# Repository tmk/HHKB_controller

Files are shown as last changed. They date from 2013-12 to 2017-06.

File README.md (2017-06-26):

Keyboard Controller Board for HHKB
==================================
This controller makes your HHKB fully programmable. You can use this with [tmk_keyboard] firmware. This will fit HHKB Pro2, Type-S and JP.

[tmk_keyboard]: https://github.com/tmk/tmk_keyboard

You can buy assembled board here. https://geekhack.org/index.php?topic=71517.0

dimension
----
141.50x36.00mm(1.6mm thick)

Update
------
- 2017/06/27: Rev.N     Fix footprint of USB: add SMD pads for frame
- 2017/05/03: Rev.M     Fix footprints of USB, LED, SKHH and DF14
- 2016/08/27: Rev.L     Enlarge TH land of USB connector
- 2016/07/03: Rev.K     Add reverse polarity protection and change foot print of D1
- 2016/01/28: Rev.J     Add TMK logo and remove C13
- 2015/12/01: Rev.I     Changed USB miniB to UX60SC-MB-5S8(through hole)
- 2015/12/01: Rev.H'    Changed lands of USB miniB to recomended size
- 2015/07/xx: Rev.H
- 2015/03/xx: Rev.G
- 2014/12/xx: Rev.F
- 2014/11/xx: Rev.E
- 2014/09/19: Rev.D
- 2014/07/28: Rev.C

LICENSE
-------
TBD

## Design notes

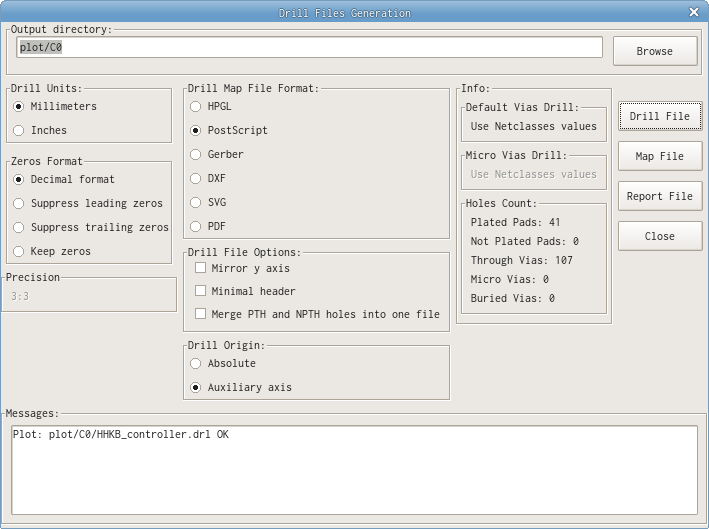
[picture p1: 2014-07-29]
plot/Drill_setting.png

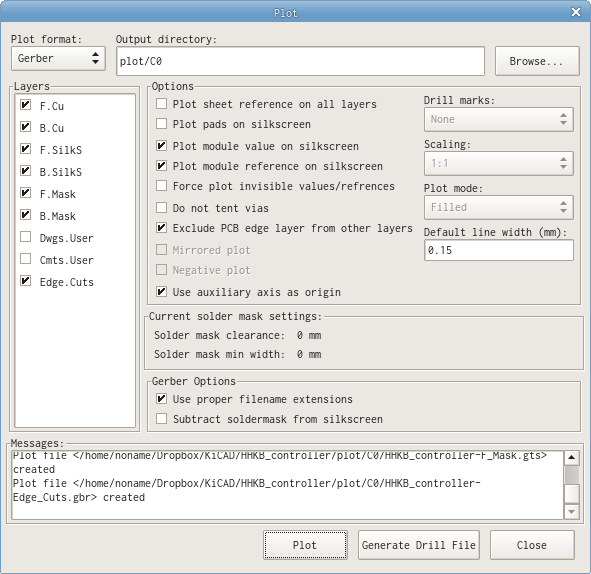
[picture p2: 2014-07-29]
plot/Plot_setting.png

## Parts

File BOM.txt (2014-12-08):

Bill of Matrials - HHKB Alt controller Rev.E
============================================

USB configuration
-----------------
USB-mini connector          1   Hirose UX60SC-MB-5ST
ATMega32U4-AU               1   TQFP44
Xtal-16MHz                  1   HC49 SMT
C22p                        2   1608    or 18pF
C1u                         1   1608 +-10%  EMK107BJ105KA-T
C0.1u                       5   1608    for decoupling
C4.7u                       1   3216    for decoupling  GRM31MF11C475ZA01
R22                         2   1608
R1K                         2   1608
LED                         1   2012 or any    SML-012WT(3020)
SW-PUSH                     1   Alps Right-angle    SKHHLPA010
JST-ZH                      1   S13B-ZR-SM4A-TF for HHKB Pro2
Hirose-DF14A                1   DF14A-15P-1.25H for HHKB JP

Bluetooth configuration
-----------------------
RN-42                       1   Roving Networks RN42-I/RM615 version 6.15   https://www.sparkfun.com/products/12574
R10K                       13   1608
R1K                         5   1608
R15K                        3   1608
MOSFET-N                    4   SOT23   IRLML6344, BS138 or any
MOSFET-P                    2   SOT23   IRLML6402 or any
LED                         2   3025/3225   Dual color LED  SEC2764C
LightPipe                   2   BIVAR SLP3-150-100-R/F
LDO3.3V                     1   SOT23   MIC5504-3.3YMTR
C1u                         2   3216    1uF X7R/B(JIS)  GRM31MR71H105KA88
NCP1402                     1   SOT23   5V Boost converter 200mA    NCP1402SN50T1G
DSchottky                   3   SOD123  Schottky diode   RB160M-30TR, PMEG2010ER
L47u                        1   6mm     Power inductor 47uH CLF6045T-470M-CA, NR6045T470M
C10u                        1   3528    tantalum/low ESR 16V 10uF or MLCC(3525)
C68u                        1   3528    tantalum/low ESR 10V 47-68uF
Lipo-charger                1   SOT23   MCP73832T-2ACI/OT(NOT MCP73831)
C4.7u                       2   3216    4.7uF X7R/B(JIS)    GRM31CB31H475KA12
R2K                         1   1608    Rprog: 2K-10K
Lipo-connector              1   JST PH2 S2B-PH-SM4-TB(LF)(SN), S2B-PH-K-S(LF)(SN)
Lipo                        1   3.7V Lipo Battery   https://www.sparkfun.com/products/339
SW-SLIDE                    1   DPDT    NKK switch SS22SDH2 http://www.mouser.jp/ProductDetail/NKK-Switches/SS22SDH2/?qs=Av7JdS0MGqKOtKhiygVtuQ%3D%3D
PPTC500mA                   1   optional

Alternatives:
3.3V Voltage Regulator:
LDO3.3V*                    1   SOT23   TAR5SB33
C0.1u*                      1   1608                0.1uF
C1u*                        1   3216, 3225 or any   1uF X7R B(JIS)
C10u*                       1   3216, 3225 or any   10uF X7R B(JIS)

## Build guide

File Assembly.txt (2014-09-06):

USB HHKB Alt controller assembly
================================
20014/08/21 Rev.C

U1          ATMega32U4
R2,R3       22Ohm
C4          1uF
C1          4.7uF(instead of 10uF)
C3,C7-10    0.1uF(for decoupling)
R4          1KOhm
C5,C6       18pF(or 22pF)
X1          16MHz
R5          1KOhm
D1          LED
CN2         JST ZH connector
J1          USB mini B receptacle
SW1         Alps tactile swtich

Following solder jumpers should be closed.
- 'amp' below C2
- 'No PWCTL'
- 'amp' marked as JP10
- 'No BT'
- 'No PPTC'

PPTC        not installed
C2          not installed
Q2_N        not installed(N-ch FET)
R15         not installed
ICSP        not installed(for debug)
PD1,PD0,GND not installed(for debug)
R17,R18     not installed(for battery monitor)
CN1         not installed(for HHKB JP)

Other components on right side part of board are also not installed.

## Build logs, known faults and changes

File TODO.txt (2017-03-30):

TODO
----
- Remove C13 pads
    DONE 2016/01(Rev.J)

- alternative connector to make component placement easy
    UX60SC-MB-5S8       whith through hole pins DONE 2015/12(Rev.I)

- Solder mask clearance
    - PCBway                0.15mm/0.075mm (0.1mm/0.050mm for green) DONE 2015/12(Rev.I)

- Logo
    - TMK logo

- Reduce components of BT part
    - use resistor array?
    - remove MOSFET

- Battery charger
    - reverse polarity protection of battery
    - connecting battery with reversed polarity definitely breaks charger chip even with a few seconds, it breaks in kindof short-circuit, fried chip may make battery fault in the end.
    - Bigger + and - marking on battery connector
    - Schottky diode between battery + and -. SS2040FL(2A/40V sod123) works for this.

DONE
----
In Rev.M:

- TACT switch footprint
    not fit to SKHH(4.5mm not 5.0mm between pins) 2017/03/24

- LED hole size
    LED D3 and D10: 1.1mm to 1mm    2017/03/30

- Beef up TH pads of USB connector
    +0.1mm 2017/03/30

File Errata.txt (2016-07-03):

Rev.B Errata and TODO
=====================
2014/07/29  Done for Rev.C

PENDING: future revision
--------
- voltage shifter   -- Another revision PCB?    -- Pending
    using RS-232C driver is better? ussable for 5V-3.3V shifter?
    power consumption?(in comparison with MOSFET shifter)

- UVCC should be connected directly to VUSB? like as VBUS.  -- no harm. Pending
    UVCC is needed only when USB is plugged.
    But it seems to be no harm even if UVCC is powered when not plugged in.

DONE:
-----
- Change drill size of LED and switch to 1.0mm -- Done 07/29

- Placement of USB receptacle    --- move Top right hole 0.2mm to the right -- Done 07/29
    USB MiniB connector should be left to around 0.3mm
    And Top right hole size should be a bit smaller

- Battery cut-off of Lipo protect circuit   -- OK 07/03
    http://www.adafruit.com/datasheets/Li-poly%20085060-2400mAh.pdf
    Charge cut-off: 4.2V
    Discharge cut-off: 2.75V

- Xtal: too far from pins. may cause EMI problem. -- Done

- Inductor is too small? -- change footprint bigger. Done
    **With NCP1402 inductor(TOKO D63LCB 100uH) whines when step-up converter is working.
    NCP1402 needs 47uH instead of 100uH.
    Sumida 47uH(6x6mm, CDRH5D28NP) doesn't whine and very calm.(07/07)
    TODO: How about TOKO D63LCB 47uH? TOKO is very cheap while Sumida one is expensive(250yen).
          Need bigger one? Sumida CDRH6D38NP 7x7mm.

    NCP1402 uses Sumida CD54-470L 47uH 0.72A
    http://www.sumida.com/products/pdf/CD54.pdf

    TOKO D63LCB 0.89A(0.43A?) marutsu
    https://www.marutsu.co.jp/data/A921CY.pdf

    Sumida CDRH5D28NP-470NC 47uH 0.62A  sengoku
    Sumida CDRH6D38NP-470NC 47uH 0.95A  sengoku
    http://www.mouser.com/ds/2/390/CDRH5D28RH125-4194.pdf
    http://www.sumida.com/products/pdf/CDRH6D38.pdf

    Datasheet of HT7750 uses ABC SR0602 inductor 47-100uH which has around Isat 0.75A-0.55A

- NCP1402 capacitor/inductor configuration -- changed values 07/03 Done
    47uH, 10uF/16V and 68uF/10V
    instead of HT7750

- schottky land pattern is too small for SOD123 -- Done 06/24
    NCP1402 uses MBR0520LT1 20V/0.5A SOD123
        Vf 0.38V
    RB521S-30   30V/0.2A                NG
    RB160M-30   30V/1A    SOD123        OK

- Capacitor polarity marking of dcdc converter -- Done 07/28
    NCP1402 may use tantalum

- R14,D7,D8 are removed -- remove from Schematic 07/03
    RN-42 LED_ACT

- R8,R9 values are reversed -- fix values on PCB 07/03
    voltage shifter 10k 15k

- RTS, CTS -- Done
    NOTE: PD5(CTS) is used as RTS and connected to CTS of RN-42. Confusing? YES.
    PD5: RTS->CTS
    PF1: CTS<-RTS
    *CTS of the module is needed to wake up from deep sleep.
- RN-42 GPIO6 for connection control    -- Done
    use PF7
    SM,4 Master mode can be controled with this port. This seems to be critical.

- Power selector doesn't work; Q4 MOSFET leaks from Lipo to USB power line. -- removed Q4 and added D11 07/03 --Done
    Schottky diode can solve simply at the expence of forward voltage drop.
    Q4 is on both USB and Lipo actually
    Q4 is on and leak when Lipo turns on; Vgs = Gnd(g) - Lipo(s)

- MCP73831  -- Done
    Add capacitor C16 on BAT  -- 07/03

- Jumper "No Lipo" remove -- 07/04  -- Done
    Not needed.

- Fix Ground fill of back side of USB receptacle -- 07/04   -- Done
    back side should be  filled

- Add JST PH-2 thourough hole pattern -- 07/04  -- Done
    JST PH-2 SMT is hard to find

- Remove ISP of RN-42 headers -- 07/04  -- Done

CANCELED:
--------
- Xtal: both TH and SMT components should be applied -- Cancel
    Not possible? bottom case touches SMT lands.

- ?current measure point should be closed by default?   -- Cancel
    YES.
    closed solder jumper cannot be created in KiCAD.

- 5V UART interface is preferable?  -- NO. 3.3V is better to connect with the module directly.
    3.3V RX_33 can not be shared between AVR and external serial adapter. -- R9 is too high and can not sink adapter hi output?

- RN-42 GPIO9 *optional     -- Not needed. iOS is not supported.(Apple authenticate co-processor is not available)
    to toggle virtual keyboard on iOS

- RN-42 GPIO11 *optional    -- Not needed. can be done with configuration
    to force HID profile

- Step-up converter(UVLO Under voltage lock out) -- misunderstood 07/04
    FACT: UVLO is a function to stop converting when charge source(not Lipo) gets to low voltage.
    FACT: Lipo has protection circuit for over discharge/charge
    NOT: HT7750A exhausts battery to voltage as 0.9V which is too low for Lipo.
    NOT: While other converter which works with Lipo UVLO is 2.1V. This is also still not save for Lipo.
    NOT: UVLO is not for Lipo protection? HT7750A should be used with normal dry battery.

Rev.C Errata
============
2014/08/12

- PTC is used only for BT
    # schematic Done 09/07
    # Canceled
- Capacitor values of NCP1402 should be reversed: 10<->68uF
    # schematic Done 09/07
- Rprog of MCP charger: Rp instead of 10K value
    # schematic Done 09/07
- C2 is not needed
    # schematic Done 09/07
- remove solder jumpers as possible
    - leave through hole jumpers and cut power line to measure current
    # remove 5V amp measure
    # remove HHKB amp measure
    # remove 3.3V amp measure
    # schematic Done 09/07
- Battery LED controlled by firmware.   
    This can indicate 'charging' status when powered and 'low voltage alart' when battery drived.
    ~CHRG: Input: read charger state,  Hi-Z: LED off, Low: LED on
    LED takes power from PSEL line; powered from USB when avaialble or battery when USB is not available and switched.
    - probably need MCP73832 instead of MCP73831
      73831 has totem pole upper Pch FET on STAT(CHRG) output and LED current leaks through its body diode when not powered.
      The leaked current gives VBUS voltage around 1.5V and controller detects USB plug wrongly in the result.
    # schematic Done 09/07  powered from PSEL

- Dual color LED for battery/power status
    - connect red to charger status/controller and green to VUSB line/Gnd.
    - yellow/orange(red+green): charging(red drived by charger)
    - green:                    powered(full charged)
    - red:                      low voltage alart(drived by controller)
    - 3025 red/green LED    http://akizukidenshi.com/catalog/g/gI-02548/
    # module 09/07
    # schematic 09/08
- Dual color LED for BT status and indicator
    - green:                    BT status is connected to RN-42 GPIO5
    - yellow:                   indicator is controlled by firmware
    - 3025 yellow/green LED http://akizukidenshi.com/catalog/g/gI-05678/
    # schematic 09/08

- Voltage divider switch is needed? its current consumption is critical?

- Solder jumpers to removing wireless function easily even if components are installed
    # Cancel 09/07     not needed on second thought

- Power control silk
    - box line around components

- Noise from boost converter
    Input capacitor 10uF causes whine sound. Removing the 10uF stops the noise.
    Tantalum 3528 one recuced a bit in comparison with ceramic one.
    With Taiyo Yuden iductor the noise seems to be reduced.
    # Use tantalum cap

- No 16MHz silk

- D1 LED footprint revise

- Bivar LED light pipe
    - TH LED footprint drill size

- use PF4 to switch ADC voltage divider
    - with Nch MOS-FET
    - http://www.eevblog.com/forum/beginners/measuring-battery-voltage-without-consuming-current/
    # schematic 09/11

PENDING
-------
- UVCC should be connected directly to VUSB? like as VBUS.  -- no harm. Pending
    UVCC is needed only when USB is plugged.
    But it seems to be no harm even if UVCC is powered when not plugged in.
- MCU at 3.3V(or directly from Lipo)
    - Voltage shifter between MCU and switch board
    - 5V booster controlled by firmware
- 3.3V regulator controlled by firmware
    - use reglator with enable pin
    - power saving controlled by firmware
Rev.D Errata
============
2014/09/22
2014/10/22
2014/10/29
2014/10/31

TODO
----
- Solder mask clearance
    - Seeed:                0.1mm min width/0.13mm clearance
    - Elecrow 5/10pcs:      0.2mm/0.2mm  http://www.elecrow.com/2-layer-10cm-10cm-max-pcb-510pcs-color-free-p-328.html
    - Elecrow small batch:  0.1mm/0.13mm http://www.elecrow.com/small-batch-of-2-layer-pcbs-50pcs-p-330.html
    - OSHPark:              not specified https://oshpark.com/guidelines

- Logo
    - TMK logo

- Paste layer for stencil
    - need to add paste layers on modules
    - need to retouch all SMT modules
    # PENDING 10/31     will do on future revision :D

- extension pins output
    - in addition to PD0 and PD1 for external
    - other pins used for BT for internal?
    - PD6(LED), PC6,7(JP), PD2,3,4,5,PE6,PF0,1,4,5,6,7(BT)
    - and 5V, GND
    - for debug(PD0, PD1), for foot pedal, extra key, LED or such?
    # PENDING   10/30   not necessity now

DONE
----
- UVCC should be connected directly to VUSB? like as VBUS.
    - no harm. how about *power consumption*?
    - UVCC is needed only when USB is plugged.
    - But it seems to be no harm even if UVCC is powered when not plugged in.
    - need patch and test on Rev.D  - OK 10/31
    # DONE 10/31    With connecting UVCC to VUSB it works without problem

- Light pipe position align
    - right one should be closer to edge
    - third LED and light pipe on middle between two?
    # CANCEL 10/30: They were aligned correctly in Rev.D

- Loose light pipe hole
    - smaller holes for LEDs
    - check datasheet of light pipe again
    # DONE 10/31    use 1.1176/0.044 instead of 0.046

- Pull-down resistor of MOSFET switch instead of pull-up
    - for HHKB key switch board power control
    - good when power down mode
    - curretnt flows to IO port through pull-up is needed to disable switch(0.5mA with 10KOhm pull-up)
    - pull up or down resistor? normally on or off?
    - difference in power consumption between them?
    # CANCEL 10/30    no significant difference
    
- Lipo voltage divider: leak current
    - Lipo -> R17 -> PF0, about 1.3V is supplied even when it turns off
    - high side Pch MOSFET switch is needed
    - and needs Nch MOSTFET to control gate of Pch
    # DONE 10/30:   PCB/shecmatic fix

- Idea: Solder jumper inside of PPTC and schotky diode
    - to save PCB space jumper can place between lands of the components
    - concern of an accidental short circuit?
    # DONE 10/30

- MCP73831 leak current from Vdd pin when not powered
    - it will need a schotky diode there.
    - VBUS of ATMega32U4 pin fails to detect of USB plug in/off event
    - LTC4054 doesn't have this problem
    - schotky also resolves charge LED problem*
    # DONE 10/30    needs a good Vf diode

- MCP73831 charge LED dim lights up when not charging
    - MCP73832 has no upside MOSFET: may resolve this?
    - schotky diode on vdd of MCP73831 resolve this problem*
    # DONE 10/30    use MCP73831 with schottky diode

- MCP73832 test
    - charge LED is ok? should not light when not charging
    - power LED should not light when not powered(need schotky diode on vdd of charger?)
    # DONE 10/30    OK with the schottky fix on Rev.D

- LED for non BT(USB controller)
    - using USB hub holes is preferable
    - for lock key and layer status
    - BT indicators can be used?
    - too tight space!
    # CANCELED 10/30: HHKB users never mind LED indicators for lock keys.

PATCH for Rev.D PCB
===================
With Rev.D to implements Bluetooth components you better have these fixes. It will work whitout fixes but these will make battery life a little bit longer.

Charger leak Fix
----------------
Without this MCU is powered with leakage current of Lipo charger MCP73831 even when swich is off.

Cut trace which runs from 'NoPPTC' solder jumper to 'PPTC' and place schottky diode on 'PPTC' lands with direction presented in picture.

ADC Switch Fix
--------------
Without this MCU is powered through ADC pin from Lipo battery.
Place components as located in picture.

http://i.imgur.com/EJhoeVUl.jpg
http://i.imgur.com/4MWi1xql.jpg
http://i.imgur.com/sklO4KDl.jpg
http://i.imgur.com/ExQrgwzl.jpg

PENDING
-------
- MCU at 3.3V(or directly from Lipo)
    - Voltage shifter between MCU and switch board
    - 5V booster controlled by firmware
- 3.3V regulator controlled by firmware
    - use reglator with enable pin
    - power saving controlled by firmware
- Xtal 8MHz
    - confirmed: USART doesn't work at baud rate 115200
    - default buad rate of RN-42 is 115200(factory setting)
    - power saving effect on MCU is not so drastic

Rev.E Errata
============
2014/12/08

- *** Rev.E BT test *** - DONE
    - with MCP73832, new Schottky, tantalum caps - DONE 12/07
        * MCP73832 doesn't leak from Vcc pin when unpluged and battery powered
            34mV vs 2.07V(MCP73831) at Vcc pin
            MCP73832 doesn't need revese protection diode D5
        * PMEG2010ER is very low VF while reverse current/voltage is high
            VF=0.96 vs 1.98(RB160M-30TR)with Fluke 175
            Anode of D11 is 680mV vs 20mV(RB160M-30TR)
            780mV is still low < 1.4V VBUS plugin detection(21.11)
                this doesn't cause false VBUS detect
                and 780mV on MCP73832 Vcc pin is also no problem.
            D5 can be removed.
    - ADC divider switching - DONE 12/07
        * Drain and Source of Q4 Pch was reversed wrongly on Rev.E.

    - reverse current from Lipo charger - DONE 12/07
        * MCP73832 has no recverse current from Vcc pin unlike MCP73831

- Rev.F design - DONE
    - current measure point - DONE 12/08
    - change value of cap 68->47    - DONE 12/08
    - PPTC land pattern: no solder jumper, use 0Ohm resistor instead - CANCEL 12/08
    - Q4 Pch FET: wrong Drain and Source - DONE 12/08
    - D5 can be removed.    - DONE 12/08

Rev.E Fix
---------
Q4 Pch FET drain and source pins are reversed stupidly in schematic and PCB on this revision.
You need to solder the FET upside down like this, really shame.
http://i.imgur.com/U6UnzaYl.jpg

Rev.F Errata
============

- Poly FUSE foot print
    Size up to 3225-3228
    Recommended pads are used already, not changed. Solder jumper is removed. 03/09

- GND pin should be connected to just one side due to thermal relief
    thin spoke thermal relief is used for reset button 03/09

Rev.G Errata
============

- Reset switch GND pin: remove thermal releif spokes on top side 
    To make good solder filet
    DONE 07/05

Rev.H Errata
============
No Errata.

- USB connector pads
    should be lessened to recoomended size?

- Remove C13
    not used anymore.

Rev.I Errata
============
No Errata.

- Remove C13
    not used anymore.

Rev.J Errata
============
No Errata.

Rev.K Errata
============
No Errata.

Change
------
- Optimize D1 foot print for reflow
- Reverse polarity protection for Lipo battery
- Change R5 value to 1.5K

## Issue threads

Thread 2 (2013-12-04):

Replace Bluetooth module

tmk, 2013-12-04:
Replace Bluegiga WT12 with Roving Networks RN-42.

RN-42:
http://www.microchip.com/wwwproducts/Devices.aspx?dDocName=en558330

Closed 2015-06-16.

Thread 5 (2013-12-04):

Rev.B: design PCB

tmk, 2013-12-04:
## Remove or Change

- Capacitor size: 10uF depens on avialability and price
- Tactile switch need larger annular ring
- debug pin pull-up resistors pads #10

## Done:
- pull up resistor R1
- HHKB connector for Pro1
- solder jumper
- SMT Xtal
- battery connector SMT component(JST PH 2) 2mm pitch
- Battery connector SMT is better? TH is very wiggly when insert and remove it.
- add mark to indicate direction of ISCP header

## Cnaceled
- add TH LED silk outiline to indicate polarity #11

Closed 2015-06-16.

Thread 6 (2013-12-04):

Power/Load switching

tmk, 2013-12-04:
FET switching between USB power source and Battery.

- FET breadboard test
- research
- MOS-FET O-ring

Closed 2015-06-16.

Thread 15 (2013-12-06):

Rev.B: Battery charger tune

tmk, 2013-12-06:
Very slow charging on Rev.A.

- charge current is tunable with R11
- fast charge time is preferable in general
- but when you want to use on phone or tablet with USB low charge current is needed(Optional)
- Bluetooth should be used on phone, tablet or mobile gadget

Closed 2015-06-16.

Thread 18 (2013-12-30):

LUFA DFU Bootloader for HHKB controller(or Teensy)

tmk, 2013-12-30:
I lost Atmel genuine bootloader for some reason during fiddling with ICSP with avrdude :) I don't know why for sure, I was just trying to read lock/fuse bits... but I must have been dumb.

So without bootloader I can't program it with USB line and very unusable. Atmel genuine bootloader for ATmega32U4 is not avaiable I had to build LUFA DFU bootloader and program it with AVRISPmkII via ICSP.

LUFA DFU bootloader is completely compatible for Atmel's, it rocks!

## build
    $ Bootloaders/DFU
    $ edit makefile
    $ make
    $ sudo avrdude -p m32u4 -c avrispmkII  -Pusb -U flash:w:BootloaderDFU.hex

## makefile for ATmega32U4(HHKB controller/Teensy)
```
--- makefile    2013-12-28 19:34:57.000000000 +0900
+++ makefile.atmega32u4 2013-12-30 13:34:03.000000000 +0900
@@ -11,10 +11,10 @@

 # Run "make help" for target help.

-MCU          = at90usb1287
+MCU          = atmega32u4
 ARCH         = AVR8
-BOARD        = USBKEY
-F_CPU        = 8000000
+BOARD        = TEENSY2
+F_CPU        = 16000000
 F_USB        = $(F_CPU)
 OPTIMIZATION = s
 TARGET       = BootloaderDFU
@@ -26,8 +26,8 @@
 # Flash size and bootloader section sizes of the target, in KB. These must
 # match the target's total FLASH size and the bootloader size set in the
 # device's fuses.
-FLASH_SIZE_KB         = 128
-BOOT_SECTION_SIZE_KB  = 8
+FLASH_SIZE_KB         = 32
+BOOT_SECTION_SIZE_KB  = 4

 # Bootloader address calculation formulas
 # Do not modify these macros, but rather modify the dependent values above.
```

tmk, 2015-06-16:
You can download binary of Atmel USB DFU bootloader here. No source codes are supplied.
http://www.atmel.com/devices/ATMEGA32U4.aspx
http://www.atmel.com/Images/megaUSB_DFU_Bootloaders.zip

While ATXmega seems to have source codes for its bootloader.
http://www.atmel.com/Images/doc8429.pdf
http://www.atmel.com/Images/AVR1916.zip

Closed 2015-06-16.

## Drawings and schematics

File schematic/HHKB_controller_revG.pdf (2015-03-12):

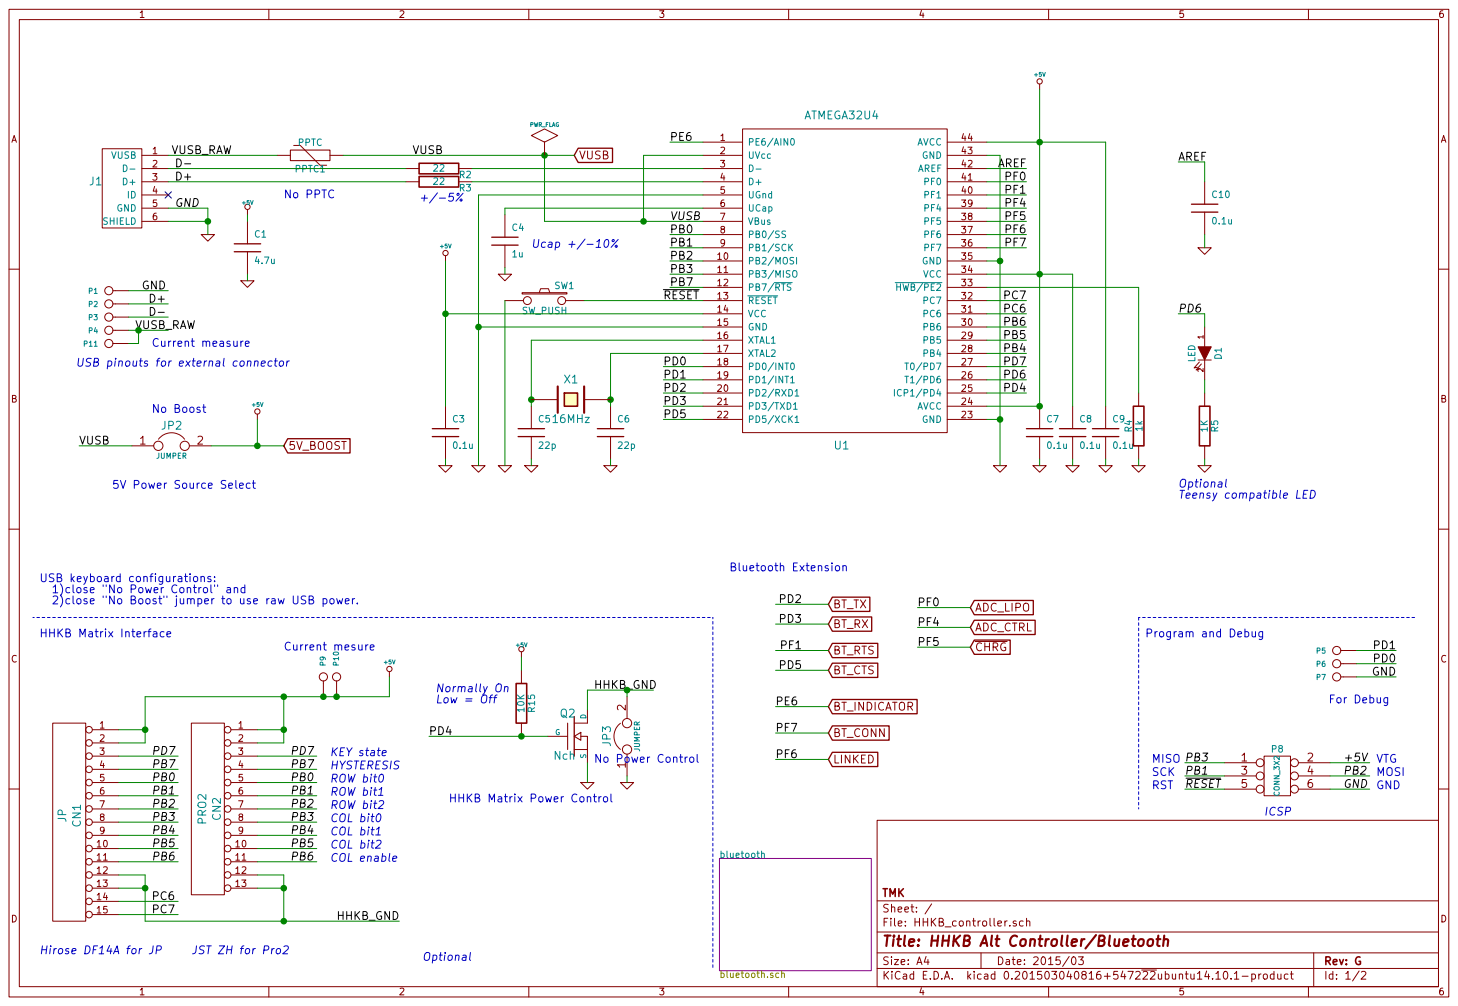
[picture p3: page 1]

P1P2P3P4 USB pinouts for external connector

1)close "No Power Control" and

+5V HHKB Matrix Power Control

File: HHKB_controller.sch Sheet: / TMK

Id: 1/2 Title: HHKB Alt Controller/Bluetooth

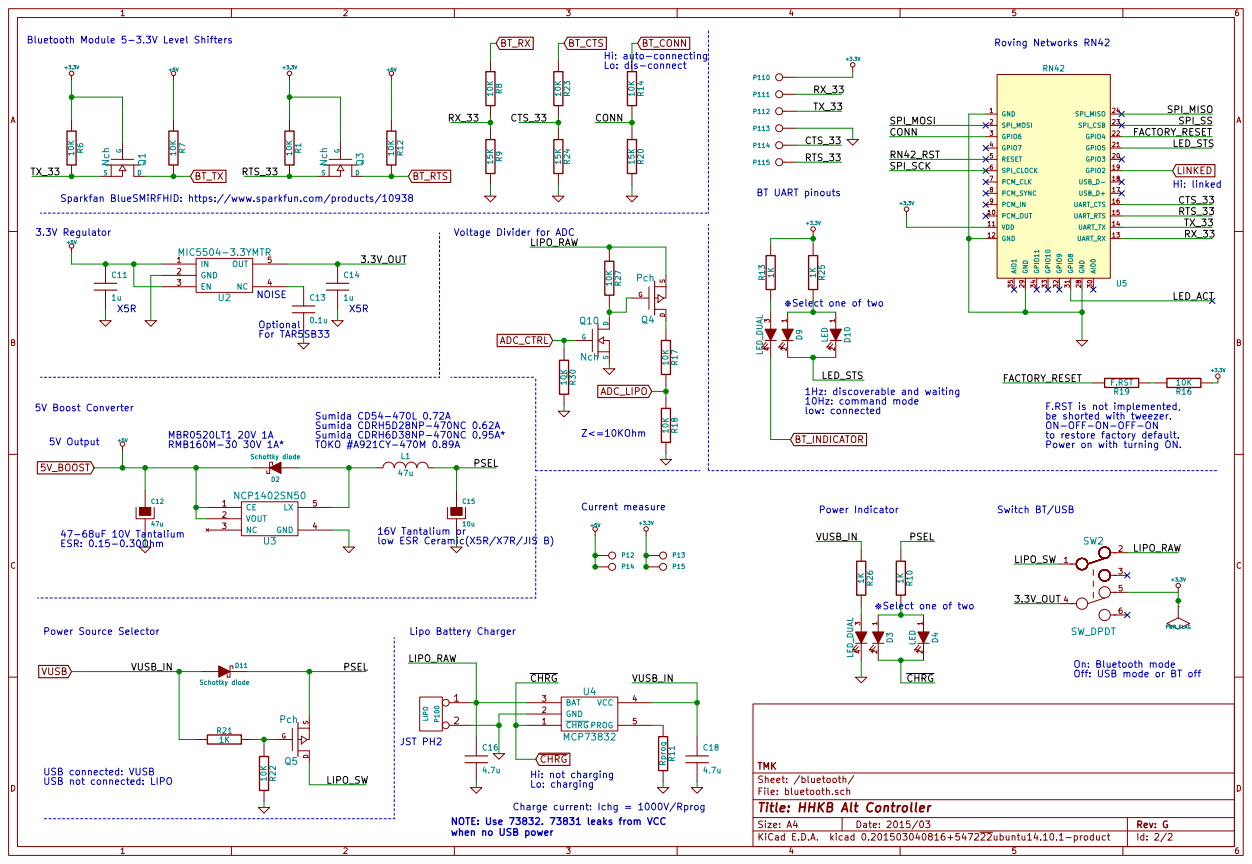
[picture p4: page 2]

Lo: dis-connect Hi: not charging

Hi: linked Hi: auto-connecting

low: connected Sparkfan BlueSMiRFHID: https://www.sparkfun.com/products/10938

Voltage Divider for ADC

Select one of two

F.RST is not implemented, be shorted with tweezer. ON-OFF-ON-OFF-ON

to restore factory default.
Power on with turning ON.

16V Tantalium or
low ESR Ceramic(X5R/X7R/JIS B)

Off: USB mode or BT off 1

Id: 2/2 Title: HHKB Alt Controller File: bluetooth.sch Sheet: /bluetooth/ TMK

USB not connected: LIPO

Charge current: Ichg = 1000V/Rprog

NOTE: Use 73832. 73831 leaks from VCC

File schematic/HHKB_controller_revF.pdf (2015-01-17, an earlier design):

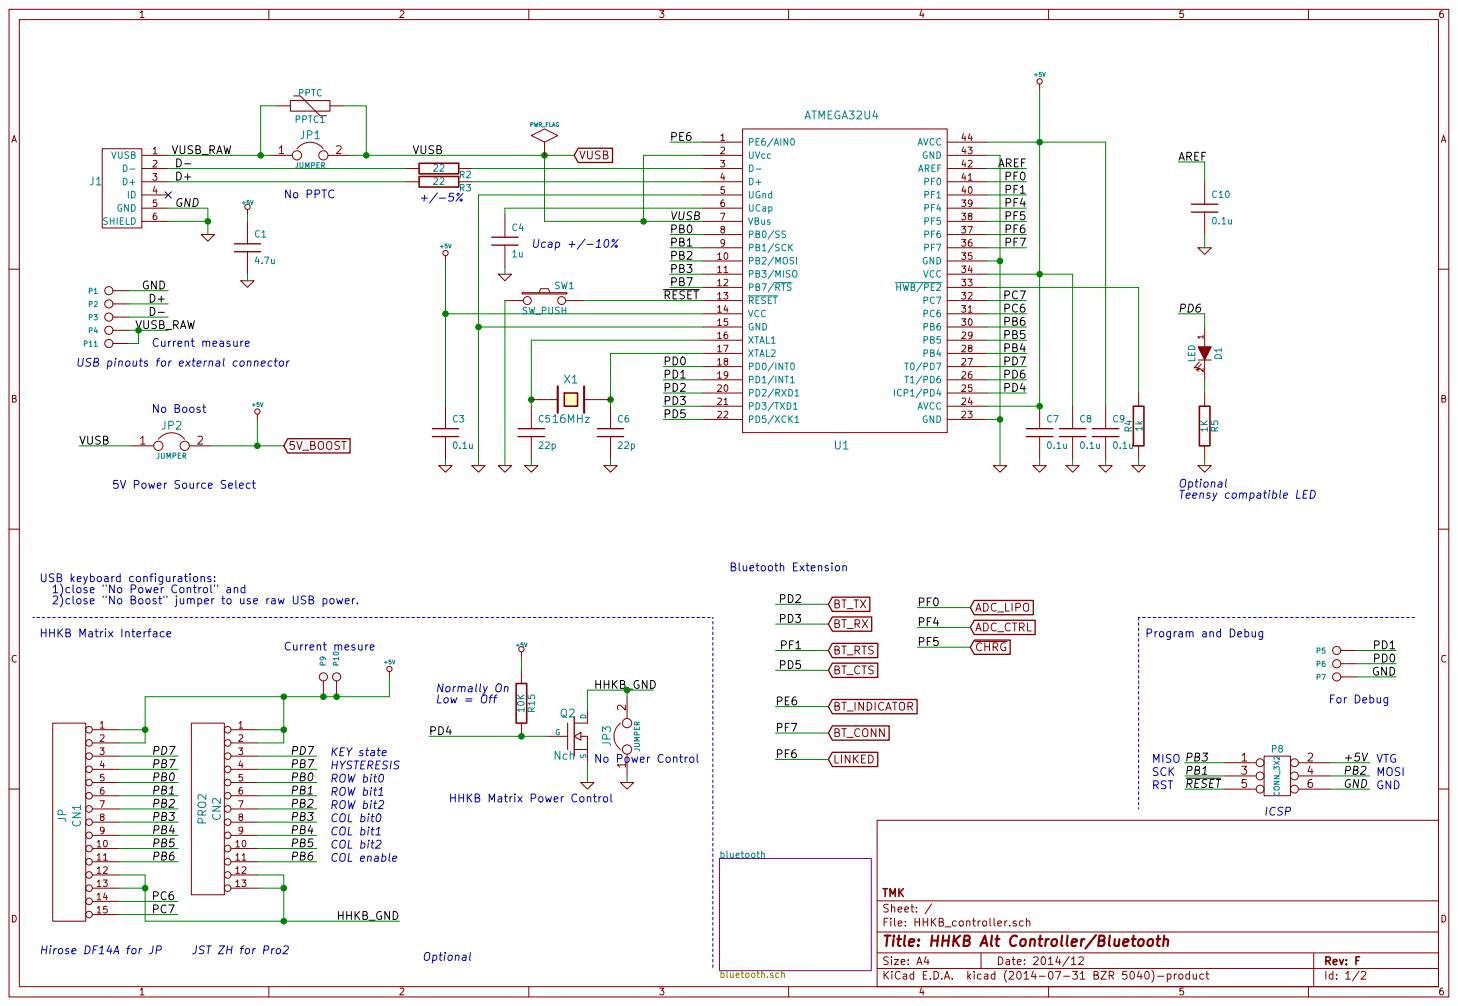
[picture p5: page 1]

P1P2P3P4 USB pinouts for external connector

1)close "No Power Control" and

+5V HHKB Matrix Power Control

File: HHKB_controller.sch Sheet: / TMK

Id: 1/2 Title: HHKB Alt Controller/Bluetooth

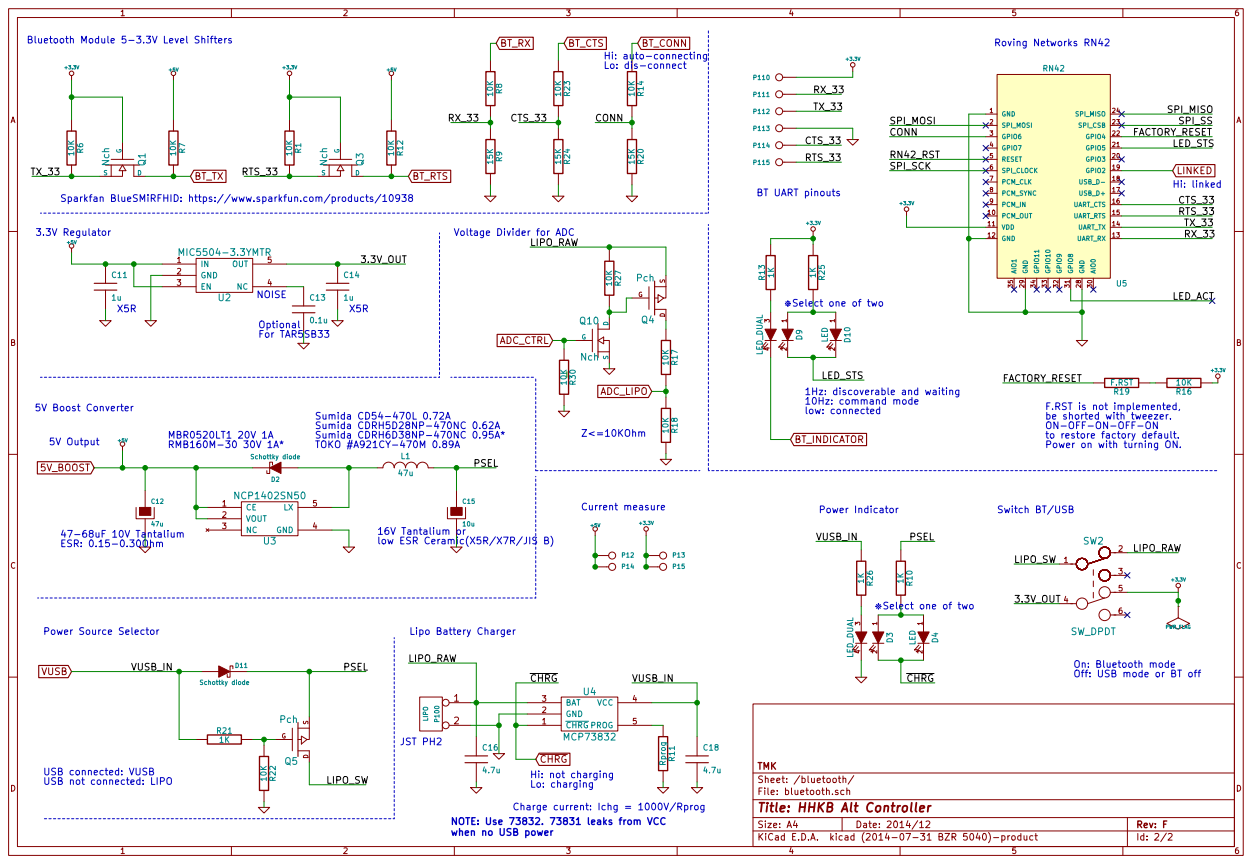
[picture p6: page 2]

Lo: dis-connect Hi: not charging

Hi: linked Hi: auto-connecting

low: connected Sparkfan BlueSMiRFHID: https://www.sparkfun.com/products/10938

Voltage Divider for ADC

Select one of two

F.RST is not implemented, be shorted with tweezer. ON-OFF-ON-OFF-ON

to restore factory default.
Power on with turning ON.

16V Tantalium or
low ESR Ceramic(X5R/X7R/JIS B)

Off: USB mode or BT off 1

Id: 2/2 Title: HHKB Alt Controller File: bluetooth.sch Sheet: /bluetooth/ TMK

USB not connected: LIPO

Charge current: Ichg = 1000V/Rprog

NOTE: Use 73832. 73831 leaks from VCC

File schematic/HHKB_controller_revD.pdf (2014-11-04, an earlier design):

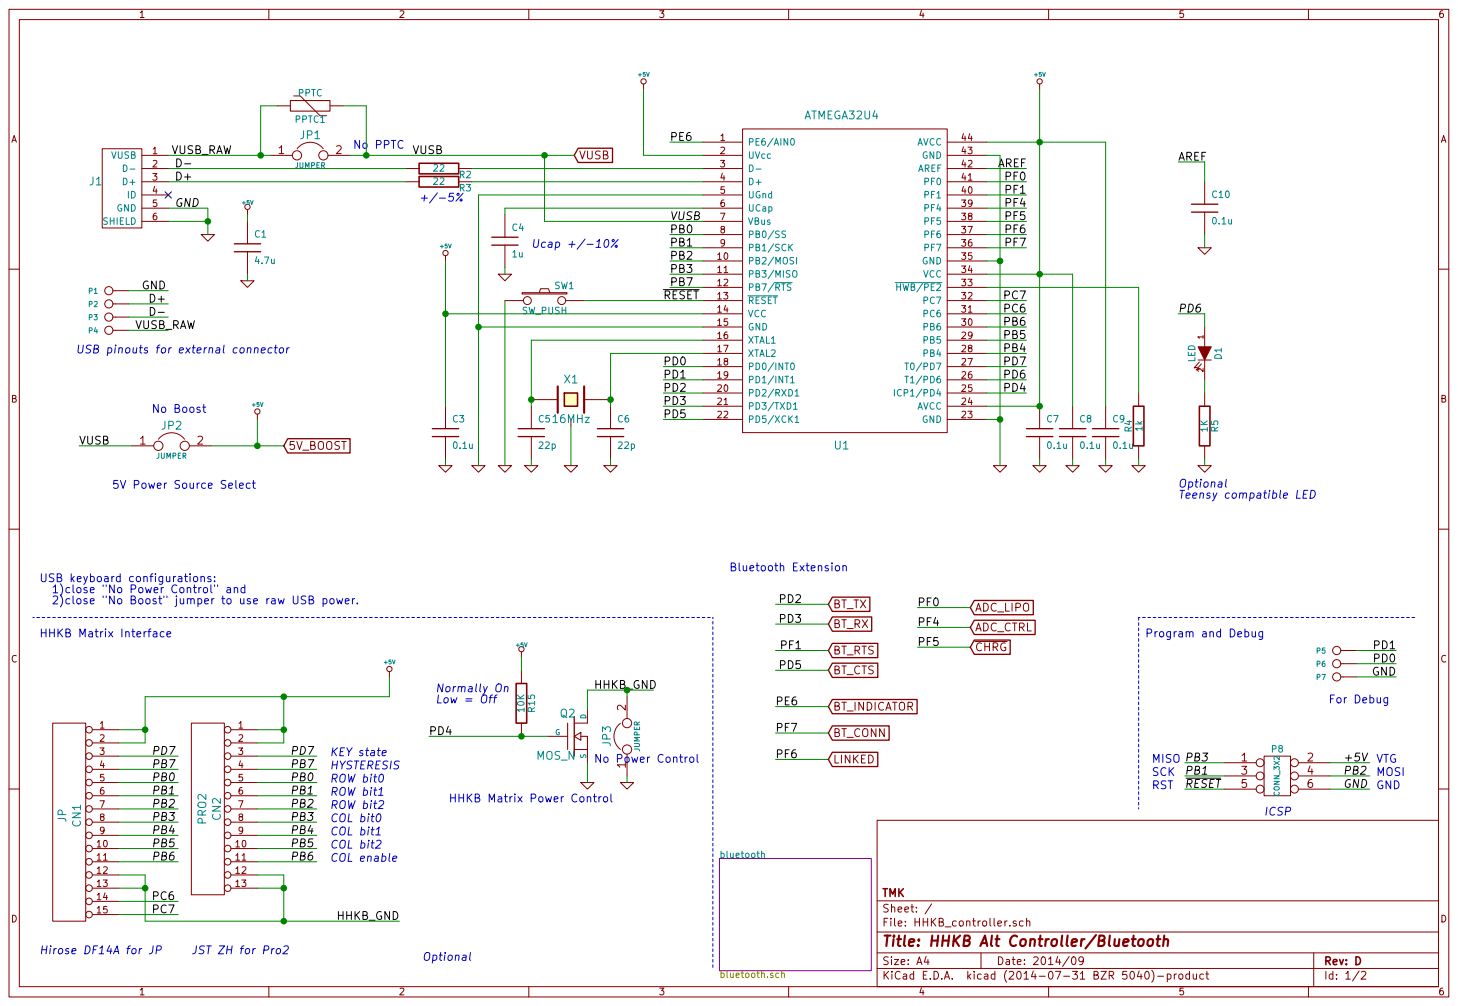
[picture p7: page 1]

P1P2P3P4 USB pinouts for external connector

1)close "No Power Control" and

+5V HHKB Matrix Power Control

File: HHKB_controller.sch Sheet: / TMK

Id: 1/2 Title: HHKB Alt Controller/Bluetooth

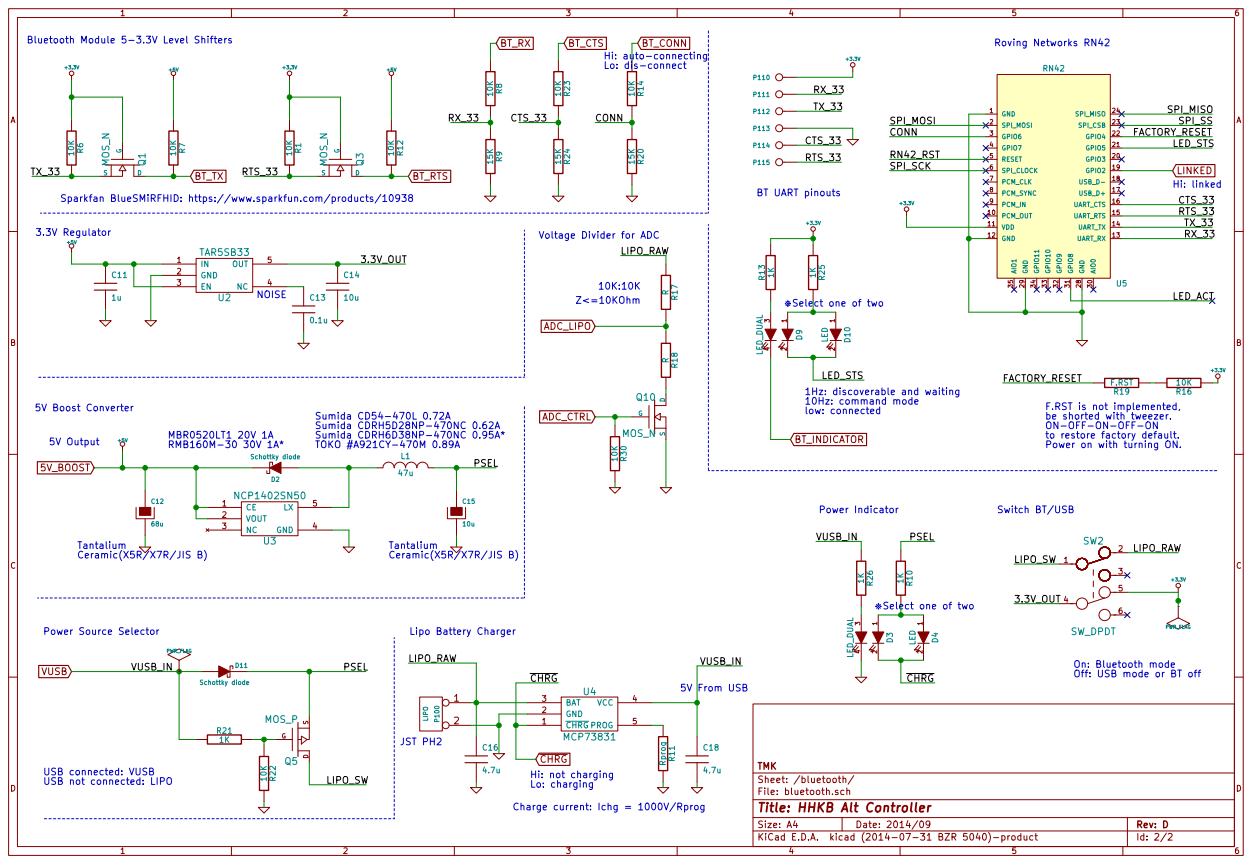
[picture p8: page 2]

Lo: dis-connect Hi: not charging

Hi: linked Hi: auto-connecting

low: connected Sparkfan BlueSMiRFHID: https://www.sparkfun.com/products/10938

Voltage Divider for ADC

Select one of two

F.RST is not implemented, be shorted with tweezer. ON-OFF-ON-OFF-ON

to restore factory default.
Power on with turning ON.

Off: USB mode or BT off 1

Id: 2/2 Title: HHKB Alt Controller File: bluetooth.sch Sheet: /bluetooth/ TMK

USB not connected: LIPO

Charge current: Ichg = 1000V/Rprog

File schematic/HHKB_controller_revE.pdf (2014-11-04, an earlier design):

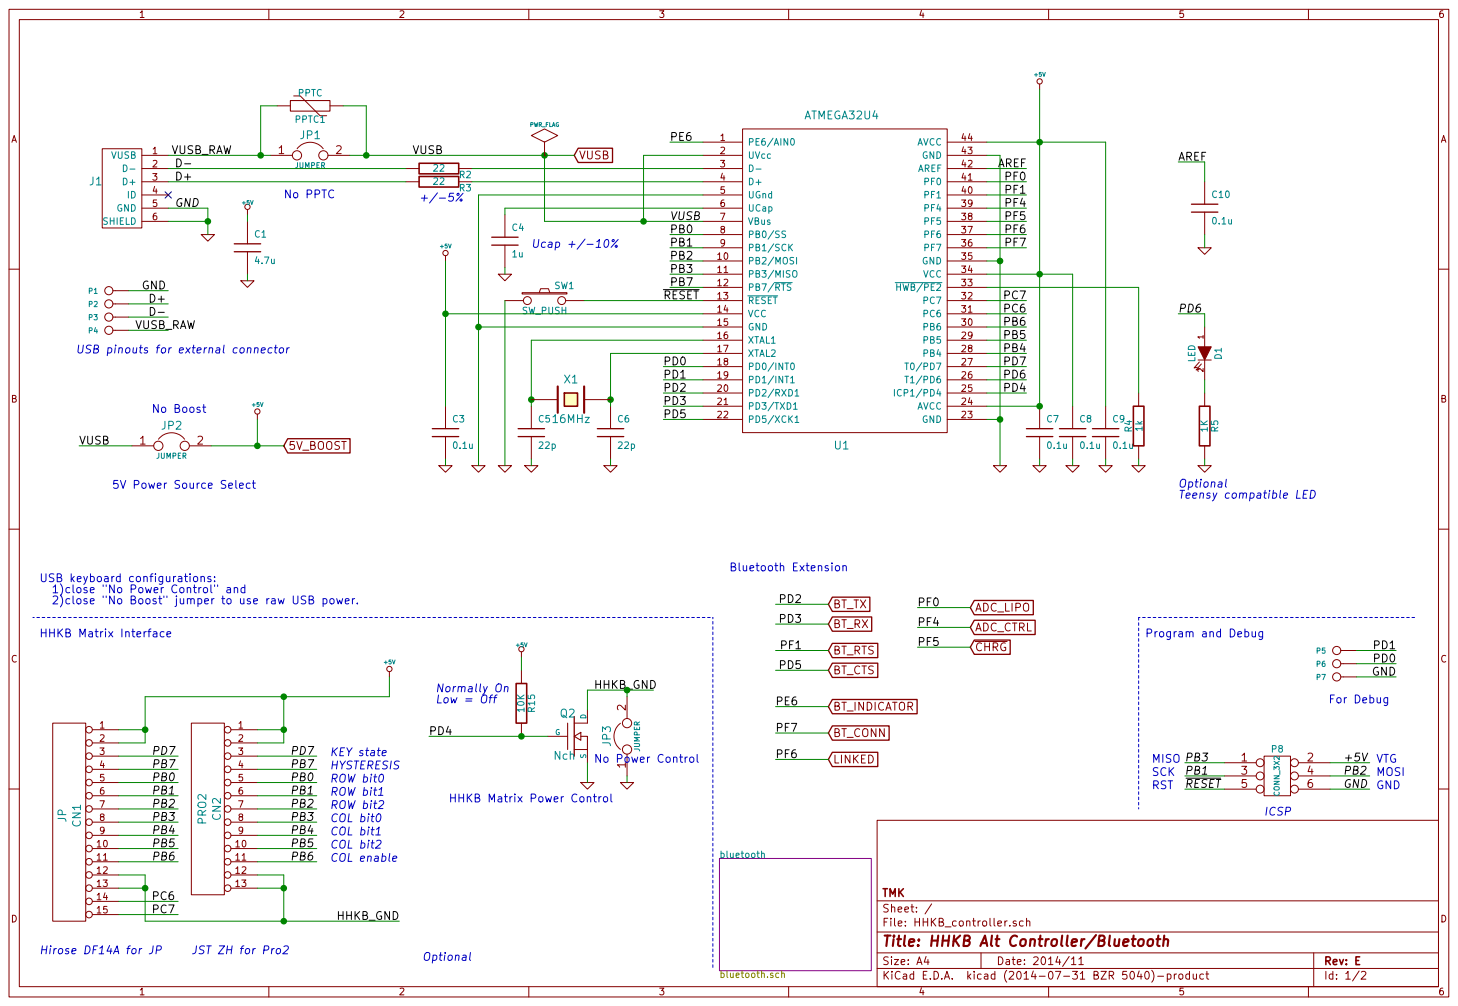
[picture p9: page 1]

P1P2P3P4 USB pinouts for external connector

1)close "No Power Control" and

+5V HHKB Matrix Power Control

File: HHKB_controller.sch Sheet: / TMK

Id: 1/2 Title: HHKB Alt Controller/Bluetooth

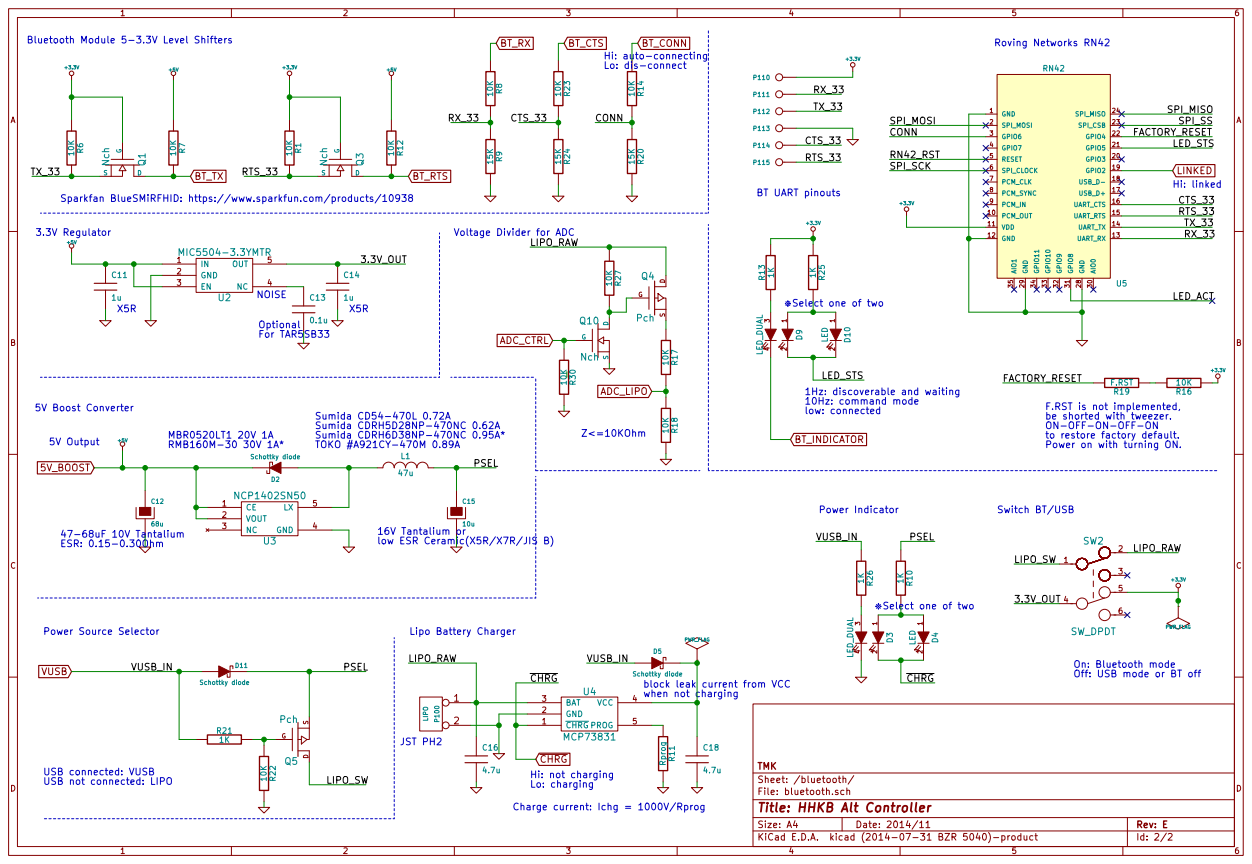
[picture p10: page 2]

Lo: dis-connect Hi: not charging

Hi: linked Hi: auto-connecting

low: connected Sparkfan BlueSMiRFHID: https://www.sparkfun.com/products/10938

Voltage Divider for ADC

Select one of two

F.RST is not implemented, be shorted with tweezer. ON-OFF-ON-OFF-ON

to restore factory default.
Power on with turning ON.

16V Tantalium or
low ESR Ceramic(X5R/X7R/JIS B)

Off: USB mode or BT off 1

block leak current from VCC
when not charging

Id: 2/2 Title: HHKB Alt Controller File: bluetooth.sch Sheet: /bluetooth/ TMK

USB not connected: LIPO

Charge current: Ichg = 1000V/Rprog

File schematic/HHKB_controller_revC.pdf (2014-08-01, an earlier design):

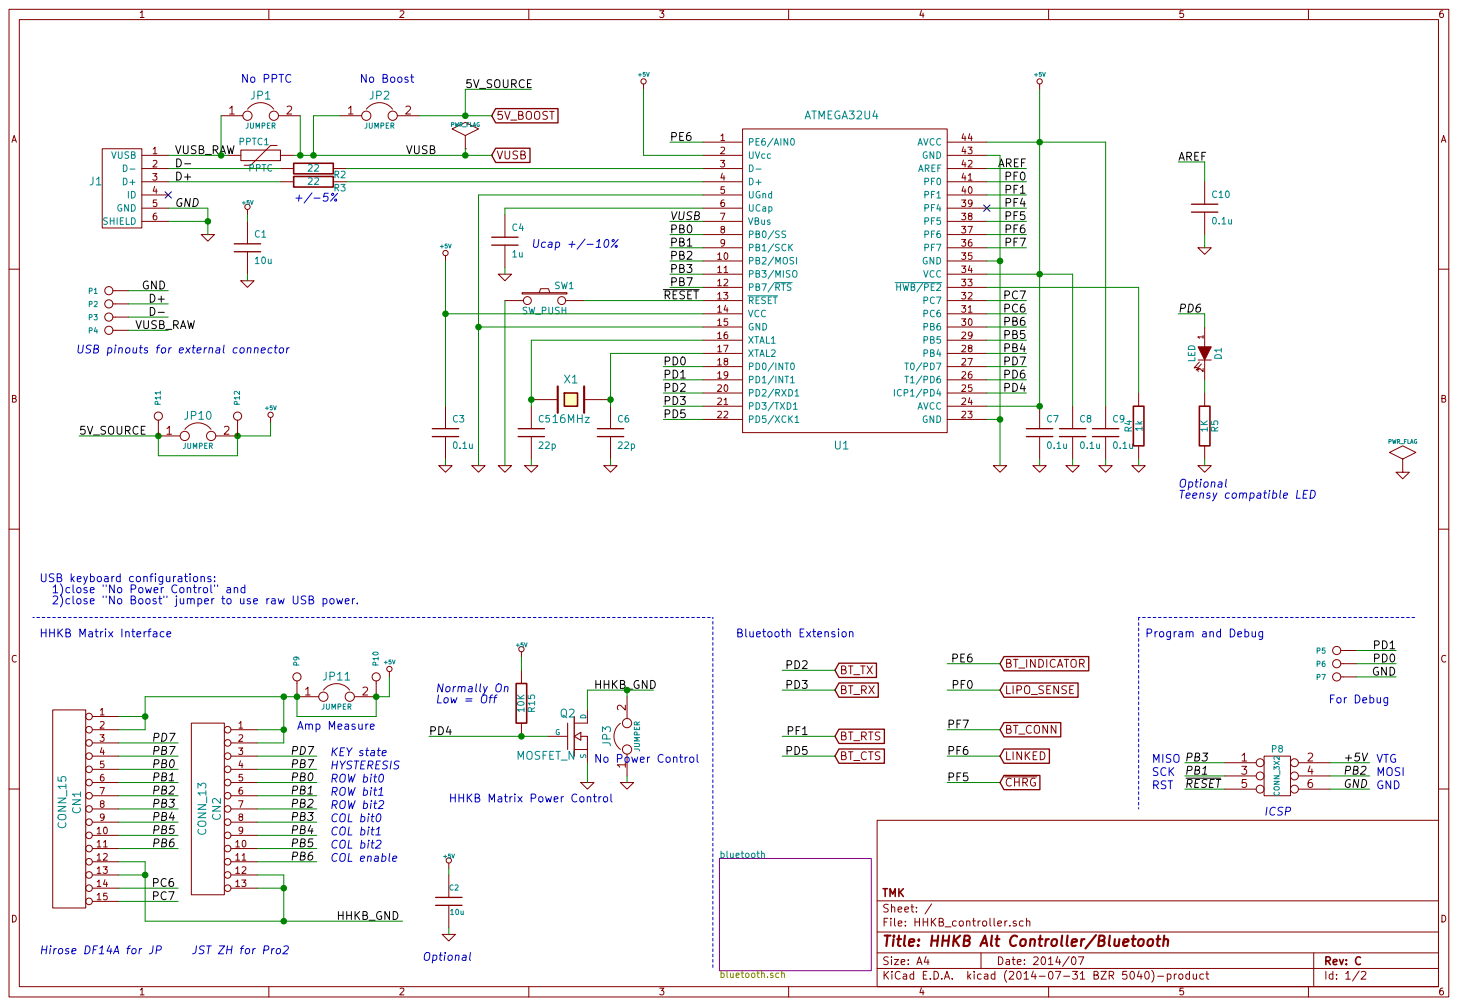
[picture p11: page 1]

P1P2P3P4 USB pinouts for external connector

1)close "No Power Control" and

+5V HHKB Matrix Power Control

File: HHKB_controller.sch Sheet: / TMK

Id: 1/2 Title: HHKB Alt Controller/Bluetooth

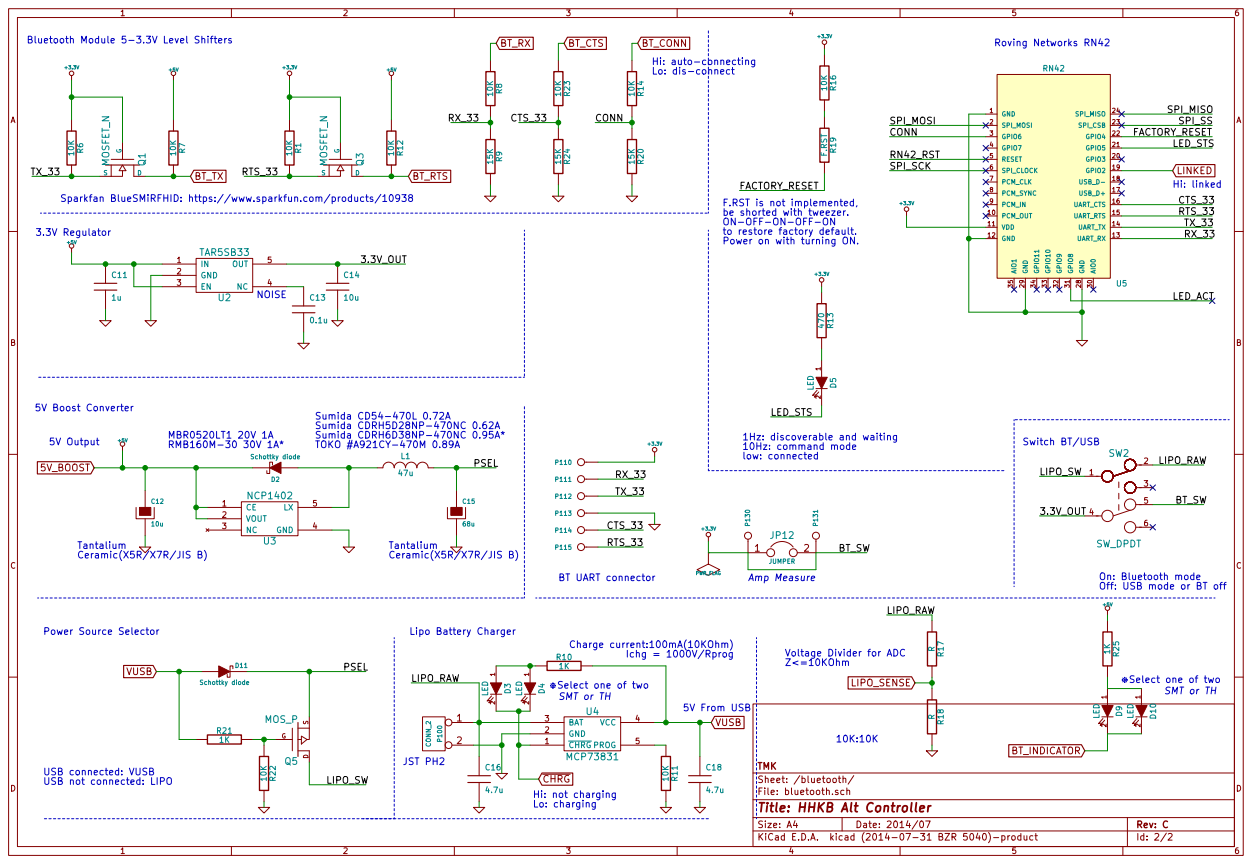
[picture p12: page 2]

BT_CONN
Hi: linked Hi: auto-connecting
Lo: dis-connect
CONN 10K R14

low: connected Sparkfan BlueSMiRFHID: https://www.sparkfun.com/products/10938

F.RST is not implemented, be shorted with tweezer. ON-OFF-ON-OFF-ON

to restore factory default.
Power on with turning ON. +3.3V470 R13

Off: USB mode or BT off 1

Voltage Divider for ADC
Z<=10KOhm

Select one of two

Id: 2/2 Title: HHKB Alt Controller File: bluetooth.sch Sheet: /bluetooth/ TMK

USB not connected: LIPO

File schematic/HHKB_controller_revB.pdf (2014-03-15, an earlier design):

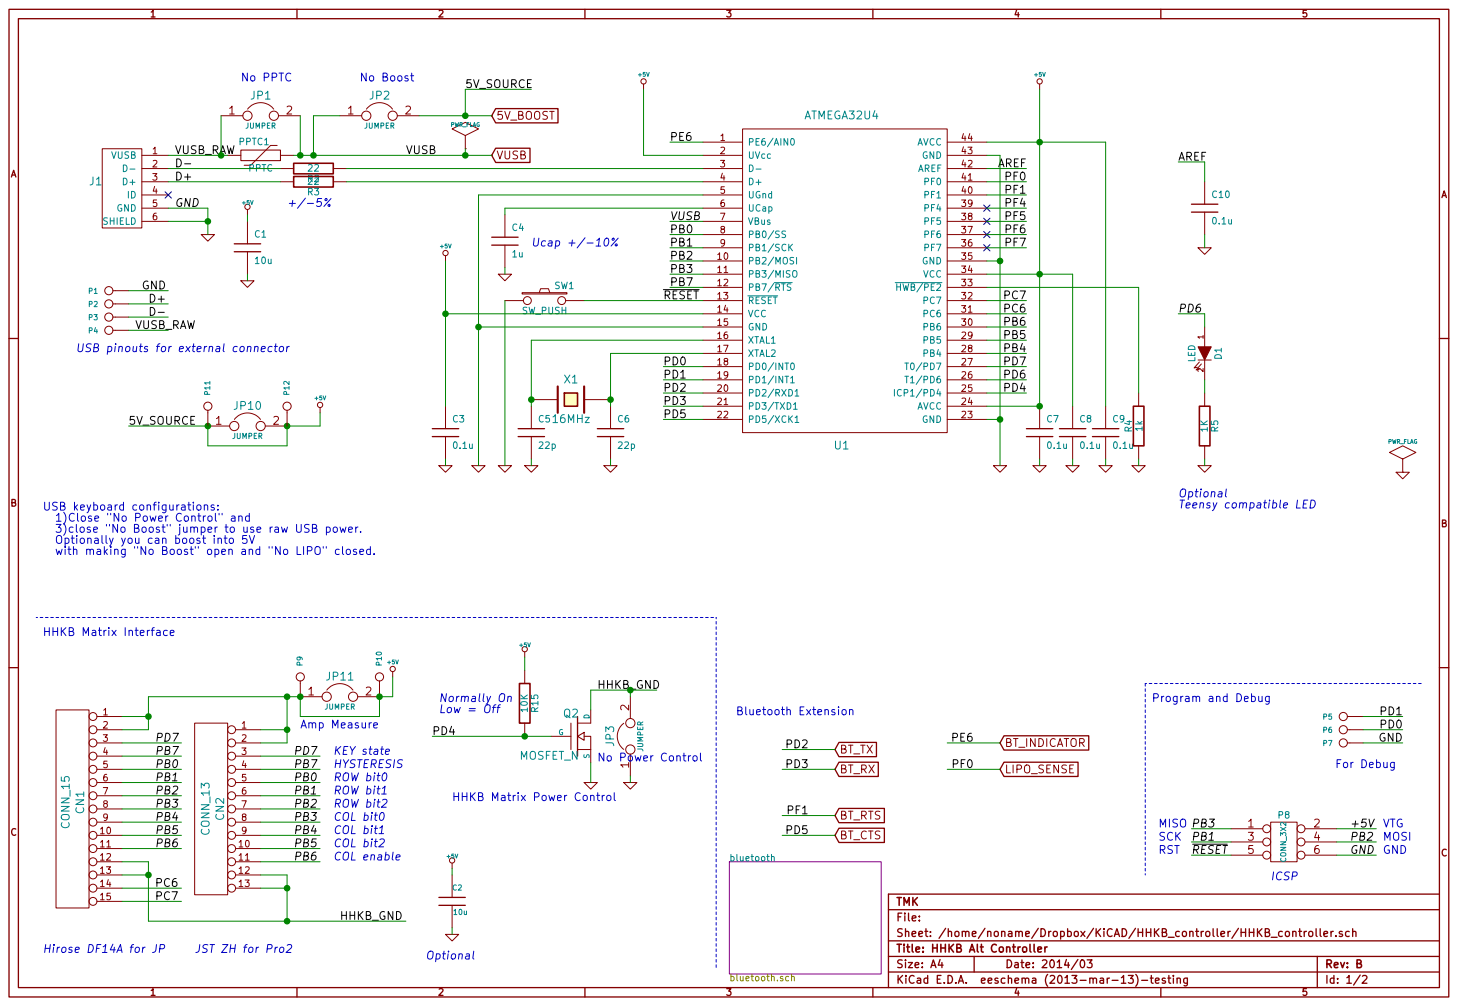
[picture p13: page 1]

P1P2P3P4 USB pinouts for external connector

1)Close "No Power Control" and
3)close "No Boost" jumper to use raw USB power.
Optionally you can boost into 5V

+5V HHKB Matrix Power Control

TMK
Sheet: /home/noname/Dropbox/KiCAD/HHKB_controller/HHKB_controller.sch File: Title: HHKB Alt Controller

KiCad E.D.A. eeschema (2013-mar-13)-testing Date: 2014/03

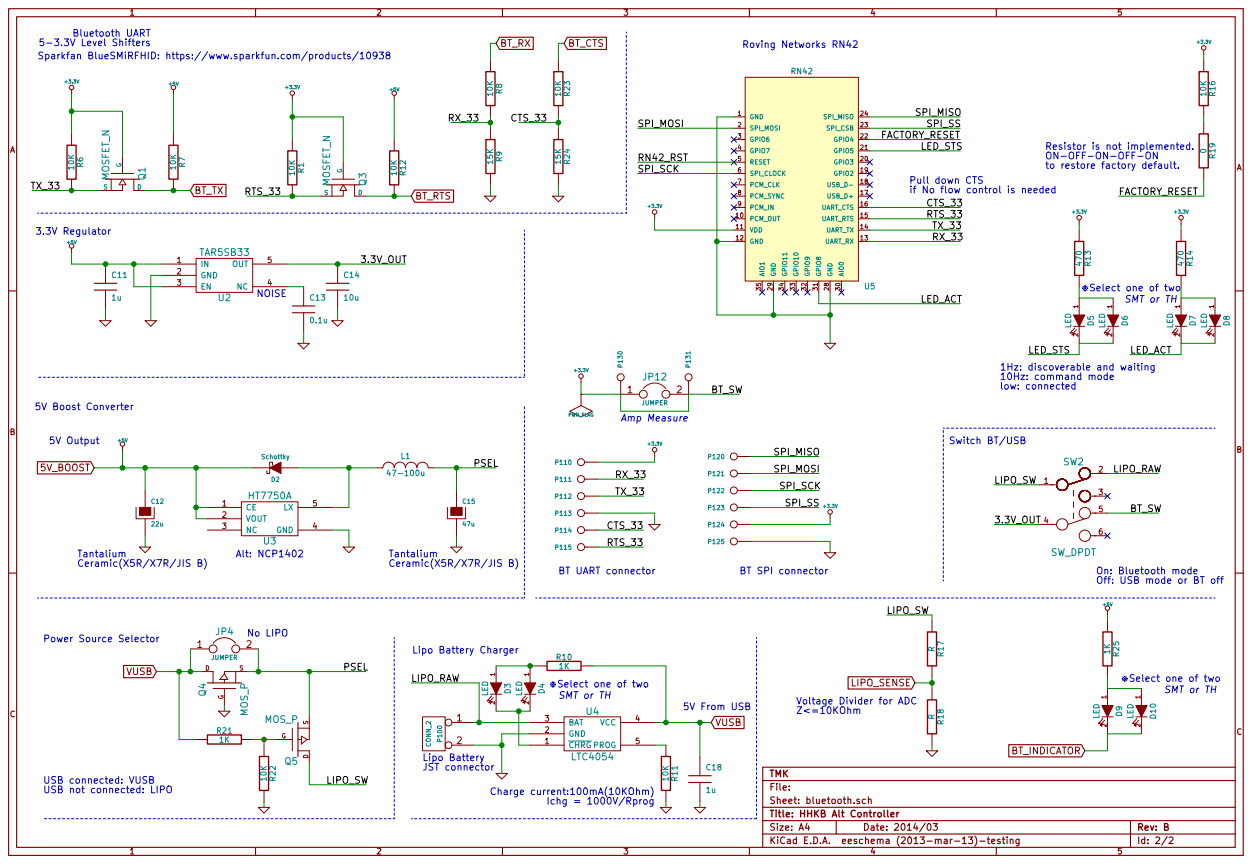
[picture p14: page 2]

3.3V Regulator Bluetooth UART
low: connected Sparkfan BlueSMiRFHID: https://www.sparkfun.com/products/10938

Resistor is not implemented.
ON-OFF-ON-OFF-ON

Select one of two
SMT or TH

On: Bluetooth mode
Off: USB mode or BT off

Voltage Divider for ADC
Z<=10KOhm

KiCad E.D.A. eeschema (2013-mar-13)-testing Date: 2014/03 1

TMK
Sheet: bluetooth.sch File: Title: HHKB Alt Controller

USB not connected: LIPO

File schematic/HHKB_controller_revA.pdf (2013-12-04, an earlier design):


1 2 D1 LED 1KR5 PD6 Optional Teensy compatible LED

USB pins for external connector

+5V Hirose PH for Pro

PD3 PD2 UART connection of Bluetooth Module

+5V HHKB Matrix Power Control

TMK kbd Sheet: /home/noname/Dropbox/KiCAD/HHKB_controller/HHKB_controller.sch File: Title: HHKB Alt Controller

KiCad E.D.A. eeschema (2013-mar-13)-testing Date: 2013/06/17


Optional Hi-Q capacitor for decouple

Lipo Battery Charger UART connected Bluetooth Modue

TMK kbd Sheet: bluetooth.sch File: Title: HHKB Alt Controller

Voltage Divider for ADC
Z<=10KOhm

KiCad E.D.A. eeschema (2013-mar-13)-testing Date: 2013/06/17

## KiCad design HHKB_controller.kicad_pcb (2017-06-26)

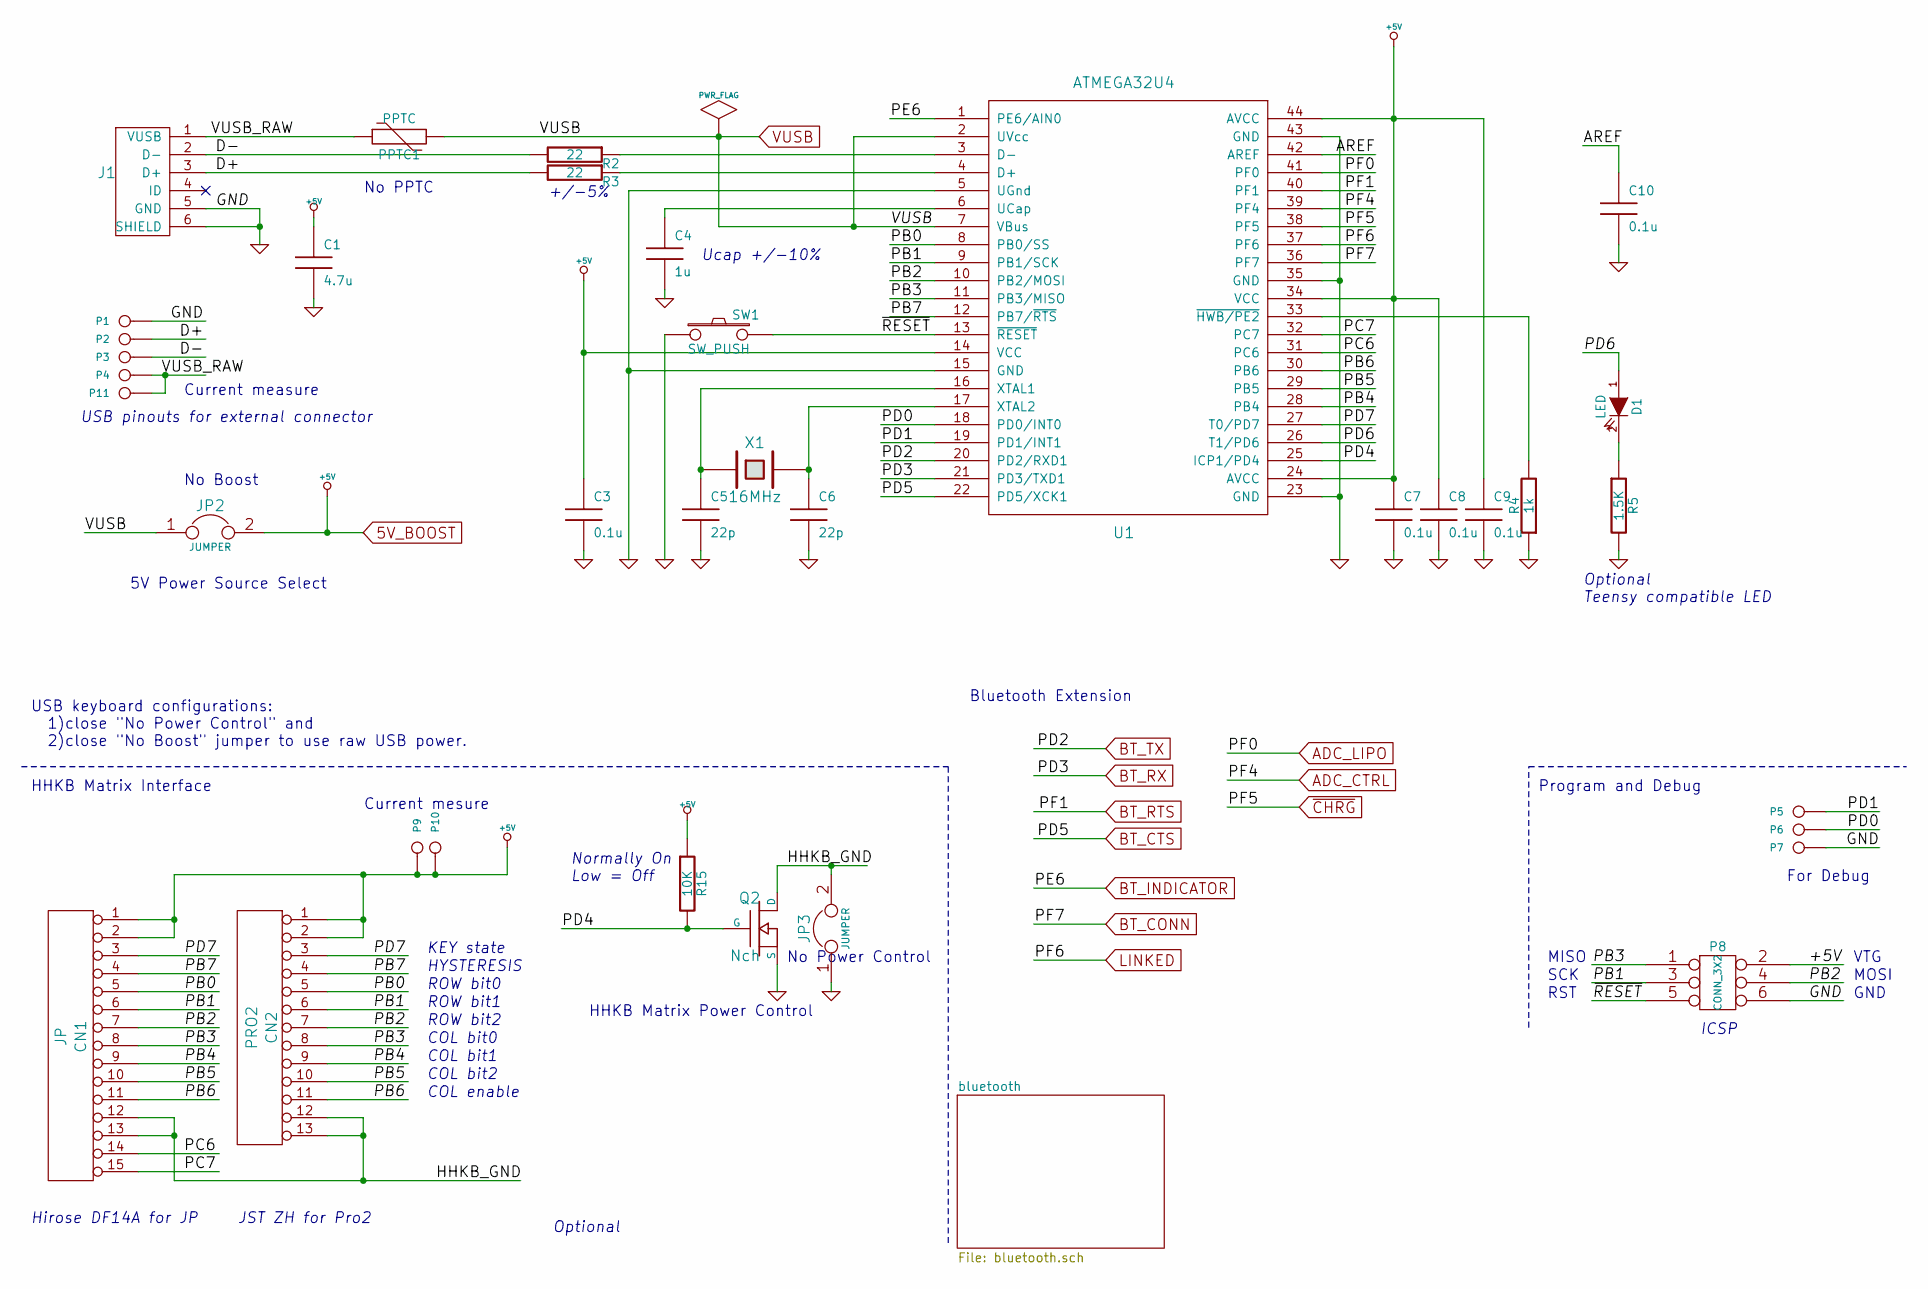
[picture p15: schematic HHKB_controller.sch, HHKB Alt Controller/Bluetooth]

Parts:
C1: 4.7u; C_3216
C3, C7, C8, C9, C10: 0.1u; C_1608
C4: 1u; C_1608
C5, C6: 22p; C_1608
CN1: JP; HHKB_JP_HRS_DF14_15P
CN2: PRO2; HHKB_PRO2_ZH13
D1: LED; LED_3020_REFLOW
J1: USB_mini_micro_B; USB_miniB_hirose_new
JP2, JP3: JUMPER; SOLDER_JUMPER_2
P1, P7: GND; PIN_1
P2: D+; PIN_1
P3: D-; PIN_1
P4: VUSB; PIN_1_SQUARE
P5: PD1; PIN_1
P6: PD0; PIN_1
P8: CONN_3X2; AVR_ICSP_3x2
P9, P10, P11: CONN_1; PIN_1
PPTC1: PPTC; PPTC_nano
Q2: Nch; MOS_FET_SOT23-3_HSOL
R2, R3: 22; R_1608
R4: 1k; R_1608
R5: 1.5K; R_1608
R15: 10K; R_1608
SW1: SW_PUSH; SW_TACT_TH_HORIZ_LOW
U1: ATMEGA32U4; QFP44
X1: 16MHz; HC-49_SMT

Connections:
5V_BOOST: C1.1, C3.1, C7.1, C8.1, C9.1, CN1.1, CN1.2, CN2.1, CN2.2, JP2.2, P8.2, P9.1, P10.1, R15.1, U1.14 (VCC), U1.24 (AVCC), U1.34 (VCC), U1.44 (AVCC); also elsewhere on the board
/AREF: C10.1, U1.42 (AREF)
/D+: J1.3 (D+), P2.1, R3.2
/D-: J1.2 (D-), P3.1, R2.2
/HHKB_GND: CN1.12, CN1.13, CN2.12, CN2.13, JP3.2, Q2.D
/PB0: CN1.5, CN2.5, U1.8 (PB0/SS)
/PB1: CN1.6, CN2.6, P8.3, U1.9 (PB1/SCK)
/PB2: CN1.7, CN2.7, P8.4, U1.10 (PB2/MOSI)
/PB3: CN1.8, CN2.8, P8.1, U1.11 (PB3/MISO)
/PB4: CN1.9, CN2.9, U1.28 (PB4)
/PB5: CN1.10, CN2.10, U1.29 (PB5)
/PB6: CN1.11, CN2.11, U1.30 (PB6)
/PB7: CN1.4, CN2.4, U1.12 (PB7/~RTS)
/PC6: CN1.14, U1.31 (PC6)
/PC7: CN1.15, U1.32 (PC7)
/PD0: P6.1, U1.18 (PD0/INT0)
/PD1: P5.1, U1.19 (PD1/INT1)
/PD4: Q2.G, R15.2, U1.25 (ICP1/PD4)
/PD6: D1.1 (A), U1.26 (T1/PD6)
/PD7: CN1.3, CN2.3, U1.27 (T0/PD7)
/VUSB_RAW: J1.1 (VUSB), P4.1, P11.1, PPTC1.1
/~RESET: P8.5, SW1.2, U1.13 (~RESET)
ADC_CTRL: U1.39 (PF4); also elsewhere on the board
ADC_LIPO: U1.41 (PF0); also elsewhere on the board
BT_CONN: U1.36 (PF7); also elsewhere on the board
BT_CTS: U1.22 (PD5/XCK1); also elsewhere on the board
BT_INDICATOR: U1.1 (PE6/AIN0); also elsewhere on the board
BT_RTS: U1.40 (PF1); also elsewhere on the board
BT_RX: U1.21 (PD3/TXD1); also elsewhere on the board
BT_TX: U1.20 (PD2/RXD1); also elsewhere on the board
GND: C1.2, C3.2, C4.2, C5.2, C6.2, C7.2, C8.2, C9.2, C10.2, J1.5 (GND), J1.6 (SHIELD), JP3.1, P1.1, P7.1, P8.6, Q2.S, R4.1, R5.2, SW1.1, U1.5 (UGnd), U1.15 (GND), U1.23 (GND), U1.35 (GND), U1.43 (GND); also elsewhere on the board
LINKED: U1.37 (PF6); also elsewhere on the board
unnamed: C4.1, U1.6 (UCap)
unnamed: C5.1, U1.16 (XTAL1), X1.1
unnamed: C6.1, U1.17 (XTAL2), X1.2
unnamed: D1.2 (K), R5.1
unnamed: R2.1, U1.3 (D-)
unnamed: R3.1, U1.4 (D+)
unnamed: R4.2, U1.33 (~HWB/PE2)
VUSB: JP2.1, PPTC1.2, U1.2 (UVcc), U1.7 (VBus); also elsewhere on the board
~CHRG: U1.38 (PF5); also elsewhere on the board

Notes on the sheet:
USB pinouts for external connector
Ucap +/-10%
+/-5%
Optional Teensy compatible LED
JST ZH for Pro2
KEY state
HYSTERESIS
ROW bit0
ROW bit1
ROW bit2
COL bit0
COL bit1
COL bit2
COL enable
Hirose DF14A for JP
ICSP
VTG
MOSI
MISO
SCK
RST
GND
Bluetooth Extension
For Debug
HHKB Matrix Power Control
Normally On Low = Off
No Power Control
No Boost
USB keyboard configurations: 1)close "No Power Control" and 2)close "No Boost" jumper to use raw USB power.
HHKB Matrix Interface
Program and Debug
Optional
5V Power Source Select
No PPTC
Current mesure
Current measure

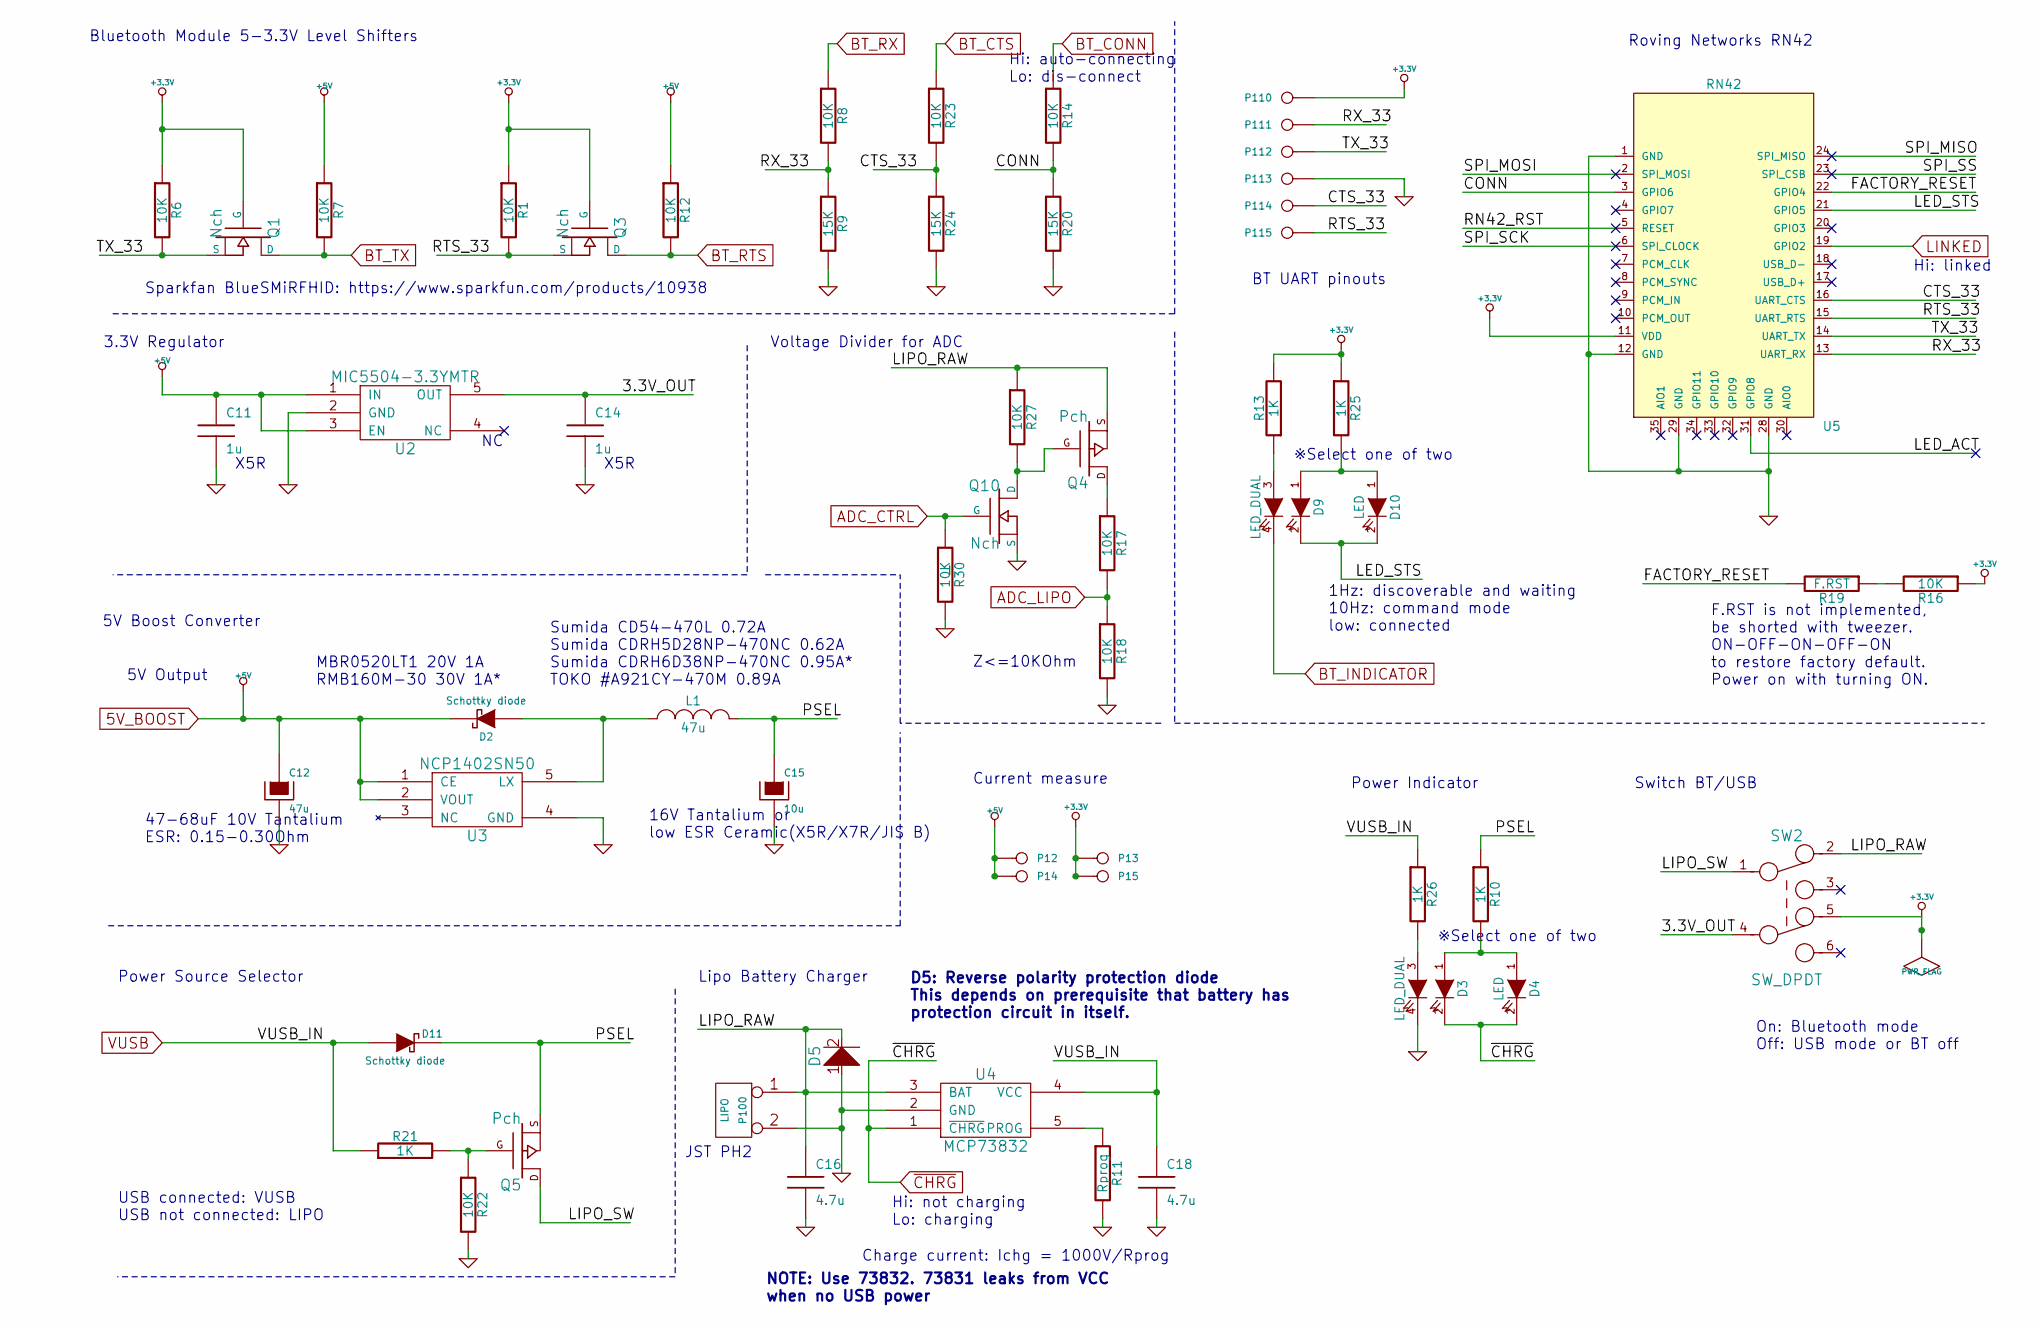
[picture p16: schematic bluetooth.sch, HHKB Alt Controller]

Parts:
C11, C14: 1u; C_3216
C12: 47u; C_3528
C15: 10u; C_3528
C16, C18: 4.7u; C_3216
D2, D11: Schottky diode; D_SOD123
D3, D9: LED_DUAL; LED_3025_DUAL
D4, D10: LED; LED_TH
D5: D; D_SOD123
L1: 47u; L_6x6MM
P12, P13, P14, P15, P110, P111, P112, P113, P114, P115: CONN_1; PIN_1
P100: LIPO; JST_PH2_SMT_TH
Q1, Q3, Q10: Nch; MOS_FET_SOT23-3_HSOL
Q4, Q5: Pch; MOS_FET_SOT23-3_HSOL
R1, R6, R7, R8, R12, R14, R16, R17, R18, R22, R23, R27, R30: 10K; R_1608
R9, R20, R24: 15K; R_1608
R10, R13, R21, R25, R26: 1K; R_1608
R11: Rprog; R_1608
R19: F.RST; R_1608_NOGUIDE
SW2: SW_DPDT; SW_MINI_SLIDE
U2: MIC5504-3.3YMTR; SOT23-5_HSOL
U3: NCP1402SN50; SOT23-5_HSOL
U4: MCP73832; SOT23-5_HSOL
U5: RN42

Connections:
5V_BOOST: C11.1, C12.1, D2.2 (K), P12.1, P14.1, R7.1, R12.1, U2.1 (IN), U2.3 (EN), U3.1 (CE), U3.2 (VOUT); also elsewhere on the board
+3.3V: P13.1, P15.1, P110.1, Q1.G, Q3.G, R1.1, R6.1, R13.2, R16.1, R25.1, SW2.5, U5.11 (VDD)
/bluetooth/3.3V_OUT: C14.1, SW2.4, U2.5 (OUT)
/bluetooth/CONN: R14.2, R20.1, U5.3 (GPIO6)
/bluetooth/CTS_33: P114.1, R23.2, R24.1, U5.16 (UART_CTS)
/bluetooth/FACTORY_RESET: R19.2, U5.22 (GPIO4)
/bluetooth/LED_ACT: U5.31 (GPIO8)
/bluetooth/LED_STS: D9.2 (K), D10.2 (K), U5.21 (GPIO5)
/bluetooth/LIPO_RAW: C16.1, D5.2, P100.1, Q4.S, R27.1, SW2.2, U4.3 (BAT)
/bluetooth/LIPO_SW: Q5.D, SW2.1
/bluetooth/PSEL: C15.1, D11.2 (K), L1.2, Q5.S, R10.1
/bluetooth/RN42_RST: U5.5 (RESET)
/bluetooth/RTS_33: P115.1, Q3.S, R1.2, U5.15 (UART_RTS)
/bluetooth/RX_33: P111.1, R8.2, R9.1, U5.13 (UART_RX)
/bluetooth/SPI_MISO: U5.24 (SPI_MISO)
/bluetooth/SPI_MOSI: U5.2 (SPI_MOSI)
/bluetooth/SPI_SCK: U5.6 (SPI_CLOCK)
/bluetooth/SPI_SS: U5.23 (SPI_CSB)
/bluetooth/TX_33: P112.1, Q1.S, R6.2, U5.14 (UART_TX)
ADC_CTRL: Q10.G, R30.1; also elsewhere on the board
ADC_LIPO: R17.2, R18.1; also elsewhere on the board
BT_CONN: R14.1; also elsewhere on the board
BT_CTS: R23.1; also elsewhere on the board
BT_INDICATOR: D9.4 (K); also elsewhere on the board
BT_RTS: Q3.D, R12.2; also elsewhere on the board
BT_RX: R8.1; also elsewhere on the board
BT_TX: Q1.D, R7.2; also elsewhere on the board
GND: C11.2, C12.2, C14.2, C15.2, C16.2, C18.2, D3.4 (K), D5.1, P100.2 (PM), P113.1, Q10.S, R9.2, R11.2, R18.2, R20.2, R22.2, R24.2, R30.2, U2.2 (GND), U3.4 (GND), U4.2 (GND), U5.1 (GND), U5.12 (GND), U5.28 (GND), U5.29 (GND); also elsewhere on the board
LINKED: U5.19 (GPIO2); also elsewhere on the board
unnamed: D2.1 (A), L1.1, U3.5 (LX)
unnamed: D3.1 (A), D4.1 (A), R10.2
unnamed: D3.3 (A), R26.2
unnamed: D9.3 (A), R13.1
unnamed: D9.1 (A), D10.1 (A), R25.2
unnamed: Q4.D, R17.1
unnamed: Q5.G, R21.2, R22.1
unnamed: Q4.G, Q10.D, R27.2
unnamed: R11.1, U4.5 (PROG)
unnamed: R16.2, R19.1
VUSB: C18.1, D11.1 (A), R21.1, R26.1, U4.4 (VCC); also elsewhere on the board
~CHRG: D3.2 (K), D4.2 (K), U4.1 (~CHRG); also elsewhere on the board

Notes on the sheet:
JST PH2
47-68uF 10V Tantalium ESR: 0.15-0.30Ohm
16V Tantalium or low ESR Ceramic(X5R/X7R/JIS B)
5V Boost Converter
3.3V Regulator
Bluetooth Module 5-3.3V Level Shifters
Lipo Battery Charger
Roving Networks RN42
Charge current: Ichg = 1000V/Rprog
5V Output
BT UART pinouts
Voltage Divider for ADC
F.RST is not implemented, be shorted with tweezer. ON-OFF-ON-OFF-ON to restore factory default. Power on with turning ON.
1Hz: discoverable and waiting 10Hz: command mode low: connected
Sparkfan BlueSMiRFHID: https://www.sparkfun.com/products/10938
Power Source Selector
USB connected: VUSB USB not connected: LIPO
※Select one of two
Switch BT/USB
On: Bluetooth mode Off: USB mode or BT off
MBR0520LT1 20V 1A RMB160M-30 30V 1A*
Sumida CD54−470L 0.72A Sumida CDRH5D28NP-470NC 0.62A Sumida CDRH6D38NP-470NC 0.95A* TOKO #A921CY-470M 0.89A
Hi: linked
Hi: auto-connecting Lo: dis-connect
Hi: not charging Lo: charging
Power Indicator
Z<=10KOhm
X5R
NOTE: Use 73832. 73831 leaks from VCC when no USB power
Current measure
D5: Reverse polarity protection diode This depends on prerequisite that battery has protection circuit in itself.

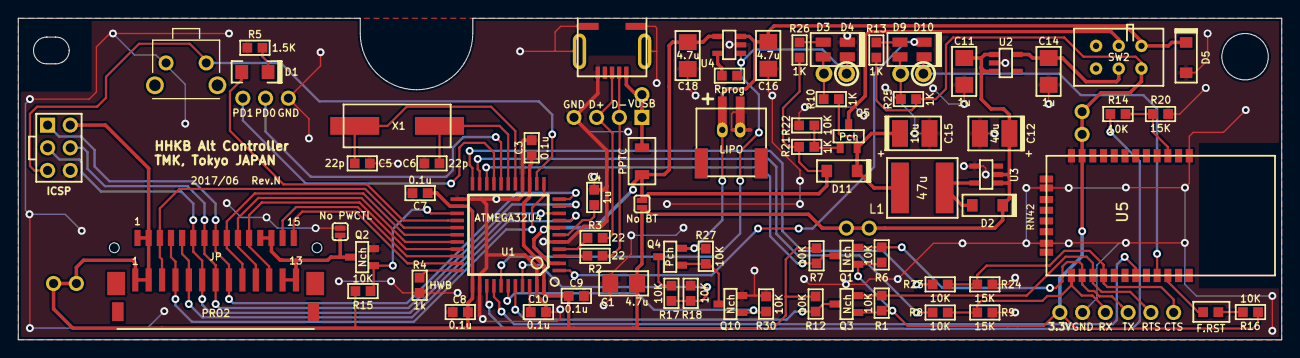
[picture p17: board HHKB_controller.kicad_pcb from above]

Board: 2 copper layers, 141.5 x 36.0 mm, 94 parts (0 on the bottom side), 63 nets.

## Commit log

2013-06-03 Add initial files
    [HHKB_controller.dsn, HHKB_controller.kicad_pcb, HHKB_controller.sch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]
2013-06-04 Coneect all component
    [HHKB_controller.kicad_pcb]
2013-06-15 Add Bluetooth module part
    [HHKB_controller.kicad_pcb, HHKB_controller.sch, bluetooth.sch]
2013-06-18 Finish Rev. A
    [HHKB_controller.kicad_pcb, HHKB_controller.sch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]
2013-12-04 Fix dimensions of outlines and move USB connector left to 0.1mm
    [HHKB_controller.kicad_pcb]
2013-12-06 Add RN42 circuit symbol
2013-12-09 Rename pdf of Rev.A circuit
2013-12-10 Fix module of HHKB pro2 SMT connector
2013-12-12 Fix pin name of JST_PH2_TH
2013-12-13 Replace Lipo connector with SMT component
    [HHKB_controller.kicad_pcb, HHKB_controller.sch, bluetooth.sch]
2013-12-18 Fix USB controller part
    [HHKB_controller.kicad_pcb, HHKB_controller.sch, bluetooth.sch]
2014-03-09 Add Power Source Selector
    [HHKB_controller.kicad_pcb, HHKB_controller.sch, bluetooth.sch]
2014-03-09 Add footprint of PPTC and SOD123
    [bluetooth.sch]
2014-03-12 Design initial Rev.B PCB
    [HHKB_controller.kicad_pcb, HHKB_controller.sch, bluetooth.sch]
2014-03-15 Clean files
    [HHKB_controller.kicad_pcb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]
2014-03-15 Clean files more
    [HHKB_controller.dsn, HHKB_controller_pro2_edge.kicad_pcb]
2014-04-11 Fix missing symbol in schematic
    [HHKB_controller.sch]
2014-07-03 Change module for Schottky diode D2
    [HHKB_controller.kicad_pcb]
2014-07-04 Fix many fixes of rev.B errata
    [HHKB_controller.kicad_pcb, HHKB_controller.sch, bluetooth.sch]
2014-07-28 Change for rev.C
    [HHKB_controller.kicad_pcb, HHKB_controller.sch, bluetooth.sch]
2014-07-28 Fix position of right top hole 0.2mm to the right
    [HHKB_controller.kicad_pcb]
2014-07-29 Change drill size for switch and LEDs and minor silk fix
    [HHKB_controller.kicad_pcb]
2014-08-01 Fix revision in schematic for rev.C
    [HHKB_controller.sch, bluetooth.sch]
2014-09-06 Update BOM and assembly instruction for rev.C
2014-09-06 Fix capacitor values for NCP1402
    [bluetooth.sch]
2014-09-06 Change value 10K to Rprog for charger resistor
    [bluetooth.sch]
2014-09-06 Remove C2
    [HHKB_controller.sch]
2014-09-06 Remove jumpers of 5V, 3.3V and HHKB amp measure
    [HHKB_controller.sch, bluetooth.sch]
2014-09-07 Change PTC route to use only for BT
    [HHKB_controller.sch, bluetooth.sch]
2014-09-07 Add submodule library
    [HHKB_controller.sch, bluetooth.sch]
2014-09-08 Change schematic for dual LEDs
    [HHKB_controller.sch, bluetooth.sch]
2014-10-23 Final fixes for Rev.D
    [HHKB_controller.kicad_pcb, HHKB_controller.sch, bluetooth.sch]
2014-10-30 Add TODO and fix BOM for Rev.E development
2014-10-30 Add D5 schottky and change C15 size and C14 value
    [HHKB_controller.kicad_pcb, HHKB_controller.sch, bluetooth.sch]
2014-10-31 Fix ADC switch and light pipe hole size
    [HHKB_controller.kicad_pcb, HHKB_controller.sch, bluetooth.sch]
2014-10-31 Fix UVCC
    [HHKB_controller.kicad_pcb, HHKB_controller.sch, bluetooth.sch]
2014-11-03 Final plot of Rev.E to order PCB
    [HHKB_controller.kicad_pcb]
2014-11-04 Add rev.D and E schematics
2014-11-04 Add keyboard_parts submodule and BOM.csv
    [BOM.csv]
2014-12-08 Update page setting for Rev.F
    [HHKB_controller.kicad_pcb, HHKB_controller.sch, bluetooth.sch]
2014-12-08 Fix Q4 P-ch FET of ADC; exchange Drain and Source
    [HHKB_controller.kicad_pcb, bluetooth.sch]
2014-12-08 Remove D5
    [HHKB_controller.kicad_pcb, bluetooth.sch]
2014-12-08 Change value of C12; 68u to 47u
    [HHKB_controller.kicad_pcb, bluetooth.sch]
2014-12-08 Add current measure pins and change pin pad size
    [HHKB_controller.kicad_pcb, HHKB_controller.sch, bluetooth.sch]
2014-12-08 Update BOM
    [BOM.csv]
2014-12-08 Add Paste layer cut out
    [HHKB_controller.kicad_pcb]
2014-12-08 Remove paste cutout from solder jumpers
    [HHKB_controller.kicad_pcb]
2015-01-17 Rev.F: Fix solder paste clearance
    [HHKB_controller.kicad_pcb]
2015-03-08 Remove solder jumper for Polyfuse
    [HHKB_controller.kicad_pcb, HHKB_controller.sch, bluetooth.sch]
2015-12-01 Change USB miniB 5ST lands to recommended
    [HHKB_controller.kicad_pcb]
2015-12-01 Change USB miniB footprint to 5S8
    [HHKB_controller.kicad_pcb]
2015-12-02 Change solder mask clearace for PCBWay
    [HHKB_controller.kicad_pcb]
2015-12-02 Fix paste layer of USB miniB 5S8
    [HHKB_controller.kicad_pcb]
2016-01-27 Remove unused C13 of MIC5504 voltage regulator
    [HHKB_controller.kicad_pcb, HHKB_controller.sch, bluetooth.sch]
2016-01-28 Add TMK logo
    [HHKB_controller.kicad_pcb]
2016-07-03 Change foot print of D1 and Add D5
    Change pad size of LED(D1) for proper reflow
    Add D5 schottky diode for reverse polarity protection
    [HHKB_controller.kicad_pcb, HHKB_controller.sch, bluetooth.sch]
2016-08-27 Enlarge TH land of USB connector
    [HHKB_controller.kicad_pcb]
2017-03-30 Change LED, USB connector and TACT switch(Rev.M)
    [HHKB_controller.kicad_pcb]
2017-05-02 Fix footprints for HRS DF14 and SKHH
    [HHKB_controller.kicad_pcb]
2017-06-26 Fix USB footprint: add SMD pads for frame
    [HHKB_controller.kicad_pcb]
